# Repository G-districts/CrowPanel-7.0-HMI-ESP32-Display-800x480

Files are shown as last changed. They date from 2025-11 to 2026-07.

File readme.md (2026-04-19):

### 1, Product picture

7.0_hmi_esp32_display

### 2, Product version number

| | Hardware | Software | Remark |
| ---- | --- | --- | --- |
| 1 | V1.0 | V1.0 | old |
| 1 | V2.0 | V2.0 | old |
| 1 | V3.0 | V3.0 | latest |

**Version 2.0** adds an automatic download feature over Version 1.0, eliminating the need to press boot+reset again before downloading the program.

**Version 3.0** adds touch timing control based on Version 2.0 to prevent touch failures. When writing programs, you need to build upon the Version 2.0 program to implement the timing control logic.

  PCA9557 Out;
  
  Out.reset();
  
  Out.setMode(IO_OUTPUT);  
  
  Out.setState(IO0, IO_LOW);
  
  Out.setState(IO1, IO_LOW);
  
  delay(20);
  
  Out.setState(IO0, IO_HIGH);
  
  delay(100);
  
  Out.setMode(IO1, IO_INPUT);

### 3, product information

- Model: 7.0 inch -CrowPanel ESP32 display
- Main Processor: ESP32-S3-WROOM-1-N4R8
- Resolution: 800*480
- Flash: 4MB
- PSRAM:8MB
- Touch Type: Capacitive Touch Screen
- Display Type: TN Panel
- Screen: TFT-LCD Screen
- Display driver: EK9716BD3 & EK73002ACGB
- External power supply: DC5V-2A
- Interface: 2\*UART0,2\*GPIO,2\*I2C,1\*Battery
- Button: BOOT Button and Reset Button
- Active Area: 153.84\*85.63mm(W*H)
- Working Temperature: -20℃～70℃
- Storage Temperature: -30℃～80℃

### 4, Use the driver module

| Name | dependency library |
| ---- | --- |
| LVGL | lvgl/lvgl@8.3.3 |

### 5,Quick Start

##### Arduino IDE starts

1.Download the library files used by this product to the 'libraries' folder.

C:\Users\Documents\Arduino\libraries\



2.Open the Arduino IDE

arduino1

3.Open the code configuration environment and burn it



##### ESP-IDF starts

1.Right-click on an empty space in the project folder and select "Open with VS Code" to open the project.



2.In the IDF plug-in, select the port, then compile and flash



##### PlatformIO starts

1.Right-click on an empty space in the project folder and select "Open with VS Code" to open the project.



2.In the PlatformIO plug-in, select the port, then compile and flash

platformIO

##### Micropython starts

1,Right-click on an empty space in the project folder and select "Thonny" to open the project.

thonny

2,In thonny software, select the master and port, then run the program

thonny2

### 6,Folder structure.

|--3D file： Contains 3D model files (.stp) for the hardware. These files can be used for visualization, enclosure design, or integration into CAD software.

|--Datasheet: Includes datasheets for components used in the project, providing detailed specifications, electrical characteristics, and pin configurations.

|--Eagle_SCH&PCB: Contains **Eagle CAD** schematic (`.sch`) and PCB layout (`.brd`) files. These are used for circuit design and PCB manufacturing.

|--example: Provides example code and projects to demonstrate how to use the hardware and libraries. These examples help users get started quickly.

|--factory_firmware: Stores pre-compiled factory firmware that can be directly flashed onto the device. This ensures the device runs the default functionality.

|--factory_sourcecode: Contains the source code for the factory firmware, allowing users to modify and rebuild the firmware as needed.

### 7,Pin definition

class LGFX : public lgfx::LGFX_Device
{
public:

  lgfx::Bus_RGB     _bus_instance;
  lgfx::Panel_RGB   _panel_instance;

  LGFX(void)
  {

    {
      auto cfg = _bus_instance.config();
      cfg.panel = &_panel_instance;
    
      cfg.pin_d0  = GPIO_NUM_15; // B0
      cfg.pin_d1  = GPIO_NUM_7;  // B1
      cfg.pin_d2  = GPIO_NUM_6;  // B2
      cfg.pin_d3  = GPIO_NUM_5;  // B3
      cfg.pin_d4  = GPIO_NUM_4;  // B4
    
      cfg.pin_d5  = GPIO_NUM_9;  // G0
      cfg.pin_d6  = GPIO_NUM_46; // G1
      cfg.pin_d7  = GPIO_NUM_3;  // G2
      cfg.pin_d8  = GPIO_NUM_8;  // G3
      cfg.pin_d9  = GPIO_NUM_16; // G4
      cfg.pin_d10 = GPIO_NUM_1;  // G5
    
      cfg.pin_d11 = GPIO_NUM_14; // R0
      cfg.pin_d12 = GPIO_NUM_21; // R1
      cfg.pin_d13 = GPIO_NUM_47; // R2
      cfg.pin_d14 = GPIO_NUM_48; // R3
      cfg.pin_d15 = GPIO_NUM_45; // R4
    
      cfg.pin_henable = GPIO_NUM_41;
      cfg.pin_vsync   = GPIO_NUM_40;
      cfg.pin_hsync   = GPIO_NUM_39;
      cfg.pin_pclk    = GPIO_NUM_0;
      cfg.freq_write  = 15000000;
    
      cfg.hsync_polarity    = 0;
      cfg.hsync_front_porch = 40;
      cfg.hsync_pulse_width = 48;
      cfg.hsync_back_porch  = 40;
    
      cfg.vsync_polarity    = 0;
      cfg.vsync_front_porch = 1;
      cfg.vsync_pulse_width = 31;
      cfg.vsync_back_porch  = 13;
    
      cfg.pclk_active_neg   = 1;
      cfg.de_idle_high      = 0;
      cfg.pclk_idle_high    = 0;
    
      _bus_instance.config(cfg);
    }
            {
      auto cfg = _panel_instance.config();
      cfg.memory_width  = 800;
      cfg.memory_height = 480;
      cfg.panel_width  = 800;
      cfg.panel_height = 480;
      cfg.offset_x = 0;
      cfg.offset_y = 0;
      _panel_instance.config(cfg);
    }
    _panel_instance.setBus(&_bus_instance);
    setPanel(&_panel_instance);

  }
};

 #define TOUCH_GT911_SCL 20//20
 #define TOUCH_GT911_SDA 19//19

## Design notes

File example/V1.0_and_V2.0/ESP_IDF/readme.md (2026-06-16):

### Here is a case study of the esp_idf platform, for actual use please refer to the wiki link for instructions.

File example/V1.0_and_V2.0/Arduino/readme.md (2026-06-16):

### Here is a case study of the arduino platform, for actual use please refer to the wiki link for instructions.

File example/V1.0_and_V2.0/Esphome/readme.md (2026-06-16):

### Here is a case study of the esphome platform, for actual use please refer to the wiki link for instructions.

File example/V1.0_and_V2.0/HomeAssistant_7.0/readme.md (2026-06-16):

# Libraries Overview

## **Adafruit_Sensor-master**
Adafruit Sensor Library provides drivers for various sensors such as accelerometers, gyroscopes, and more.

## **Arduino_GFX**
Arduino GFX is a library designed for rendering graphics on displays connected to Arduino boards.

## **async-mqtt-client-develop**
Async MQTT Client Development Library enables asynchronous communication with MQTT brokers using non-blocking code suitable for embedded systems.

## **AsyncTCP-master**
Async TCP Master implements an asynchronous TCP/IP stack allowing efficient network programming without blocking the main loop of your program.

## **Crowbits_DHT20**
Crowbits DHT20 Library offers support for interfacing with DHT20 temperature and humidity sensors via I2C protocol.

## **DHT-sensor-library-master**
DHT Sensor Library Master facilitates reading data from DHT series digital temperature & humidity sensors through GPIO pins on microcontrollers.

## **FT6236**
FT6236 Driver Library handles touch screen input detection and processing based on capacitive touch technology often found in smartphones and tablets.

## **gt911-arduino**
GT911 Arduino Library manages touch panel inputs specifically tailored towards GT911 chipsets commonly utilized in touchscreen applications.

## **LovyanGFX**
Lovyan GFX serves as a comprehensive graphic library capable of driving multiple kinds of displays including TFTs, OLEDs among others while offering advanced features like anti-aliasing text rendering.

## **lvgl**
LVGL stands for Light and Versatile Graphics Library which focuses on providing high-performance graphical user interface solutions primarily targeted at resource-constrained environments yet scalable enough for complex GUI designs.

## **TFT_eSPI**
TFT eSPI specializes in controlling ILI9341-driven TFT displays featuring built-in SD card reader functionality along with touch screen capabilities if applicable.

## **U8g2**
U8g2 is another lightweight graphics library intended mainly for monochrome LCD/LED displays but also supports some color screens; it's known for its simplicity and ease-of-use making it ideal for beginners entering into graphical display projects.

## **UI**
User Interface component likely refers to either a set of pre-designed elements ready-to-use within your project or could denote custom-coded components forming part of larger application’s visual presentation layer.

## **XPT2046_Touchscreen**
XPT2046 Touchscreen Library deals with resistive touchscreens employing XPT2046 controller IC enabling precise touch location tracking essential for interactive interfaces.

## **lv_conf.h**
LvConf.h represents configuration header file where users can customize settings pertaining to LVGL library according to their specific requirements regarding display characteristics, memory allocation strategies amongst other tunable aspects influencing overall performance and behavior of graphical outputs generated by said library.

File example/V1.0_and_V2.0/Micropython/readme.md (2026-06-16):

### Here is a case study of the micropython platform, for actual use please refer to the wiki link for instructions.

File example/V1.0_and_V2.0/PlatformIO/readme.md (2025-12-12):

### Here is a case study of the platformIO platform, for actual use please refer to the wiki link for instructions.
## Complete code link：https://www.elecrow.com/download/product/CrowPanel/ESP32-HMI/7.0-DIS08070H/PlatformIO/CrowPanel_ESP32_7.0_PlatformIO_Project.zip

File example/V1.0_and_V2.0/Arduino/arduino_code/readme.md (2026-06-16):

# Libraries Overview

## **Adafruit_BusIO**
Adafruit BusIO is a library that provides an interface for communicating with various I/O devices over different buses like I2C, SPI, etc.

## **Adafruit_GFX_Library**
The Adafruit GFX Library is used for drawing graphics on displays connected to microcontrollers. It supports many different display types including OLEDs, LCDs, and e-paper displays.

## **Adafruit_SSD1306**
This library allows you to control SSD1306-based OLED displays using Arduino or other compatible platforms.

## **BLE**
Bluetooth Low Energy (BLE) libraries are typically used for wireless communication between devices at low power consumption levels.

## **Crowbits_DHT20**
A library specifically designed for reading data from DHT20 digital temperature and humidity sensors.

## **EEPROM**
EEPROM stands for Electrically Erasable Programmable Read-Only Memory; this library enables storing small amounts of persistent data even when the device loses power.

## **ESP32-audioI2S-master**
This library facilitates audio playback through I2S protocol on ESP32 microcontrollers, often used in projects involving sound output.

## **FFat**
FFat refers to FatFs, a generic FAT filesystem module for small embedded systems. This library helps manage storage on SD cards or similar media.

## **FS**
File System libraries provide functions for managing files and directories within the system's storage.

## **gt911-arduino-main**
Library for integrating GT911 capacitive touch screen controllers into Arduino projects.

## **LovyanGFX**
LovyanGFX is another graphics library aimed at providing high-performance rendering capabilities across various display technologies.

## **lvgl**
LVGL (Light and Versatile Graphics Library) is a free and open-source graphics library that offers advanced GUI elements suitable for embedded systems.

## **PCA9557**
PCA9557 is an I/O expander chip controlled via I2C bus - its corresponding library would allow controlling multiple GPIO pins remotely.

## **SD**
Standard SD card library enabling read/write operations on Secure Digital memory cards.

## **SD_MMC**
Similar to above but may include additional features or optimizations specific to certain models of SD/MMC cards.

## **SPI**
Serial Peripheral Interface (SPI) is a synchronous serial communication interface specification used by microcontrollers to communicate with peripheral devices such as sensors, displays, etc.

## **SPIFFS**
SPI Flash File System – a lightweight file system designed primarily for use with flash memories found in many IoT devices.

## **Ticker**
Ticker libraries usually offer precise timing functionalities useful in scheduling tasks or generating interrupts based on time intervals.

## **UI**
User Interface components could encompass anything from visual design assets to interactive elements facilitating user interaction with hardware/software applications.

## **WiFi**
Libraries dealing with WiFi connectivity protocols enabling internet access via wireless networks.

## **WiFiClientSecure**
Enhanced version of WiFiClient incorporating security measures like SSL/TLS encryption ensuring secure connections over Wi-Fi networks.

## **Wire**
Two-wire interface (TWI), also known as Inter-Integrated Circuit (I²C), is a bidirectional serial computer bus used for attaching lower-speed peripherals to processors and microcontrollers.

## **lv_conf.h**
Configuration file for LVGL library defining parameters like display resolution, color format, font sizes, widget styles, event handling mechanisms amongst others tailored per application needs.

## **UI-7.0-BLUE.rar**
This appears to be a compressed archive containing resources related to User Interface version 7.0 themed in blue colors possibly including icons, images, layouts or other graphical content necessary for creating consistent look-and-feel across application interfaces.

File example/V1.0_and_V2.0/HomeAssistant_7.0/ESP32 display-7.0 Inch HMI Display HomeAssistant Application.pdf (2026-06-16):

# Home Assistant Raspberry Pi Server Configuration

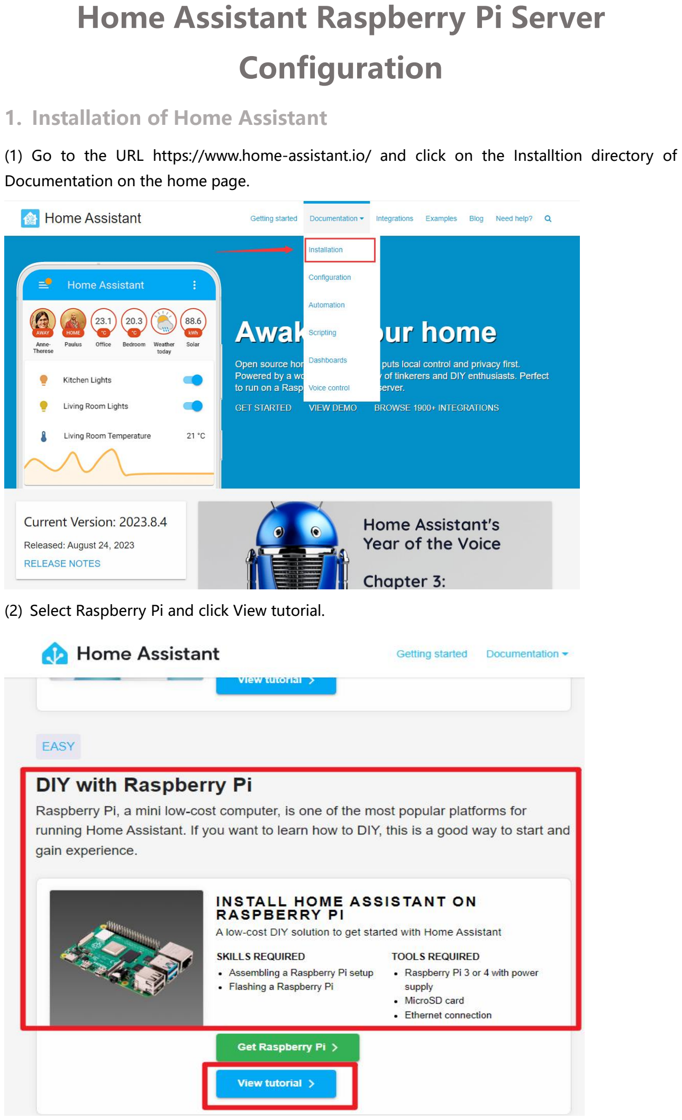
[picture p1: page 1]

## 1. Installation of Home Assistant

(1) Go to the URL https://www.home-assistant.io/ and click on the Installtion directory of Documentation on the home page.
(2) Select Raspberry Pi and click View tutorial.

## 2. Write the image to the SD card

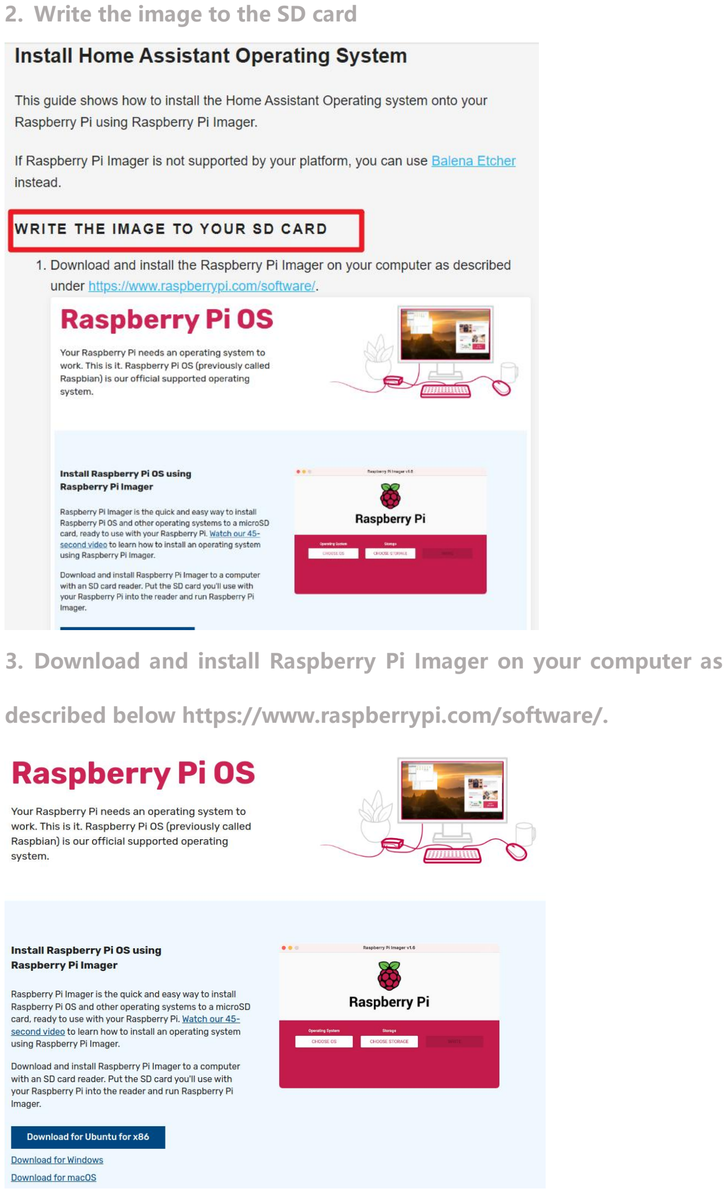
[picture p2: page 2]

## 3. Download and install Raspberry Pi Imager on your computer as

described below https://www.raspberrypi.com/software/.

4. Open Raspberry Pi Imager and select your Raspberry Pi device.

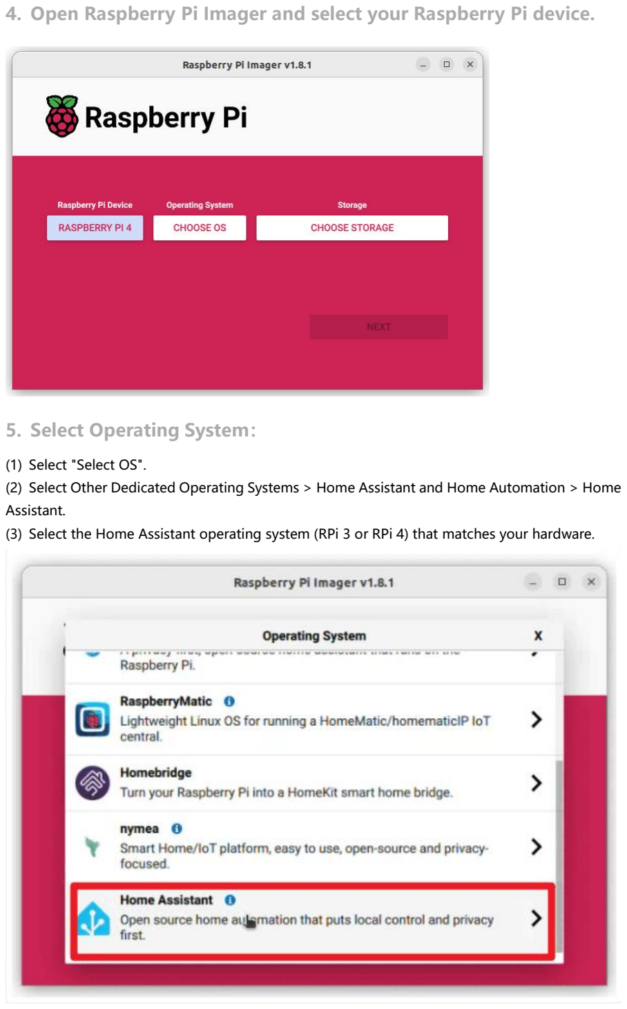
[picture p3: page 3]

## 5. Select Operating System：

(1) Select "Select OS". (2) Select Other Dedicated Operating Systems > Home Assistant and Home Automation > Home

Assistant. (3) Select the Home Assistant operating system (RPi 3 or RPi 4) that matches your hardware.

## 6. Select storage:

(1)Insert the SD card into the computer. Note:The contents of the card will be overwritten. (2)Select your SD card.

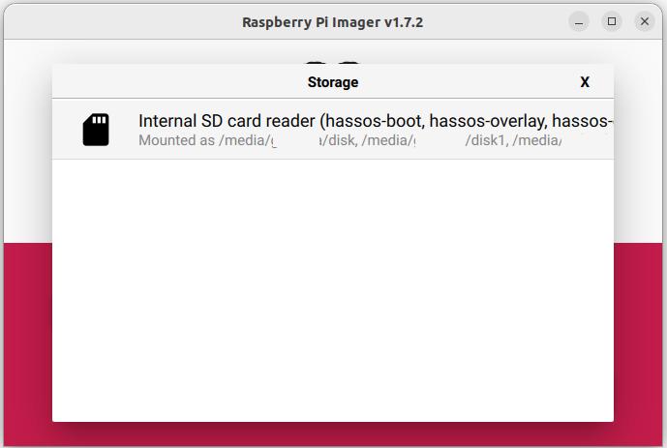
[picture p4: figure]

## 7. Write the installer to the SD card:

(1) To start the process, select Next. (2) Wait for the Home Assistant OS to write to the SD card.

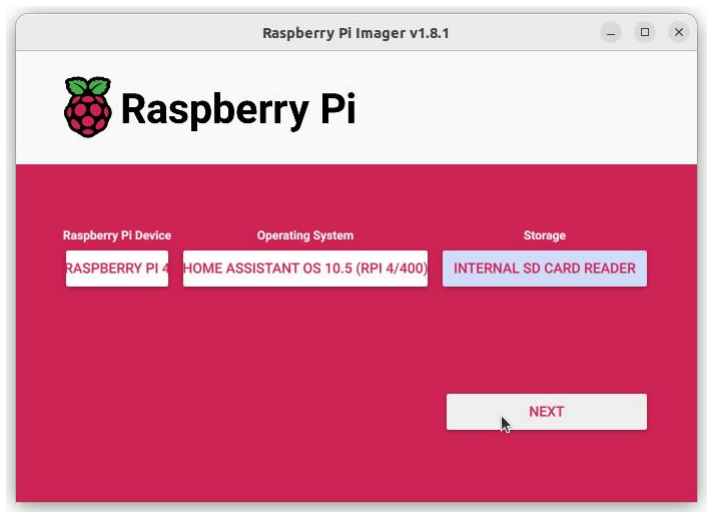
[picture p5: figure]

## 8. Eject the SD card. 9. Start Raspberry Pi

(1) Insert the SD card into the Raspberry Pi. (2) Plug in the Ethernet cable and make sure the Raspberry Pi is connected to the same network

as your computer.

(3) Connect the power supply and start the device. 10. start the Raspberry Pi, start after the completion of we can see

## the LAN ip address and port information, 8123 is the management

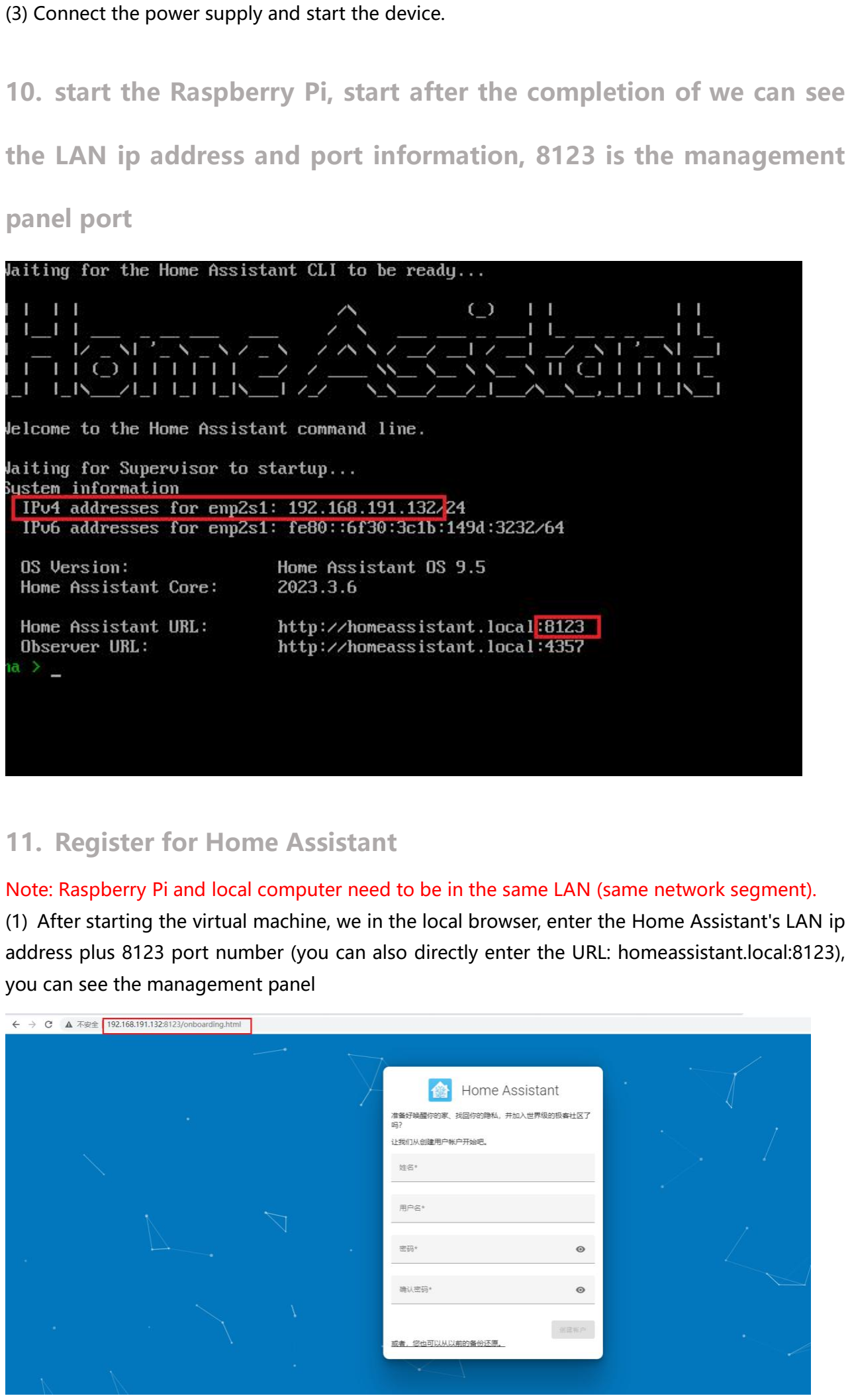
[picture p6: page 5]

## panel port

## 11. Register for Home Assistant

Note: Raspberry Pi and local computer need to be in the same LAN (same network segment). (1) After starting the virtual machine, we in the local browser, enter the Home Assistant's LAN ip

address plus 8123 port number (you can also directly enter the URL: homeassistant.local:8123), you can see the management panel

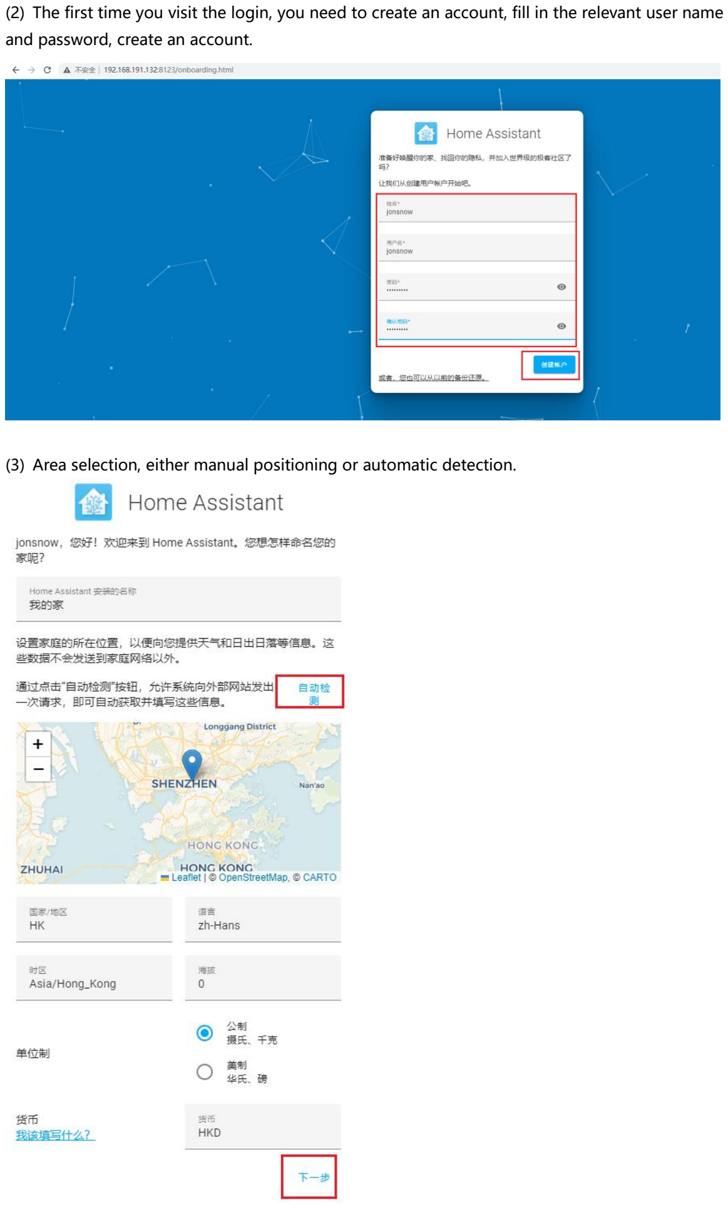
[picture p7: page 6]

(2) The first time you visit the login, you need to create an account, fill in the relevant user name and password, create an account.
(3) Area selection, either manual positioning or automatic detection.

(4) Next click Next by default

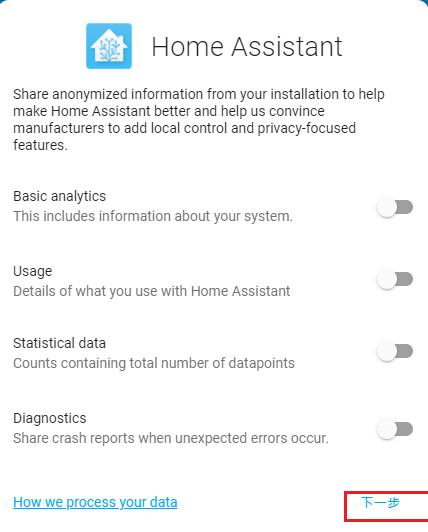
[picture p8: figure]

(5) Then click Finish, here prompted to add a smart device, you can click Finish, and then set up your own settings.

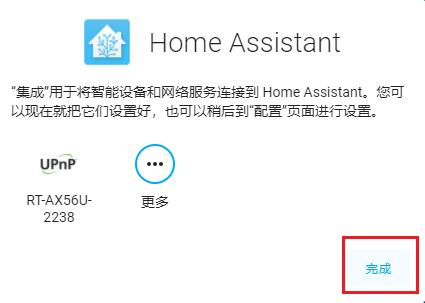
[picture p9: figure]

(6) Then you're in the control panel screen

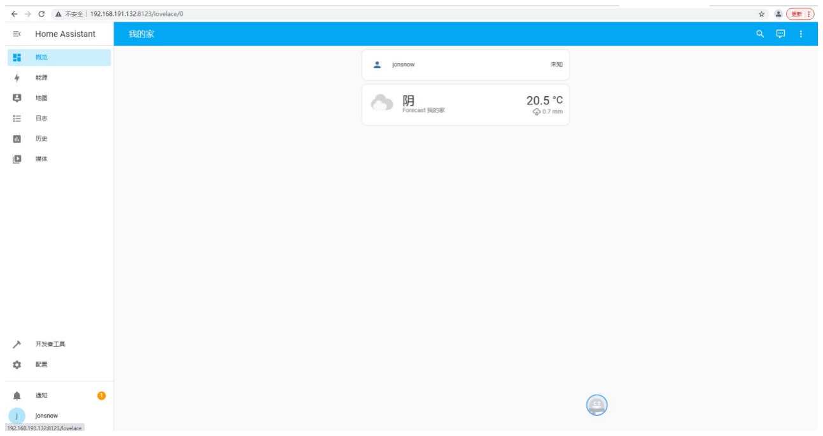
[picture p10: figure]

## 12. Configuring MQTT

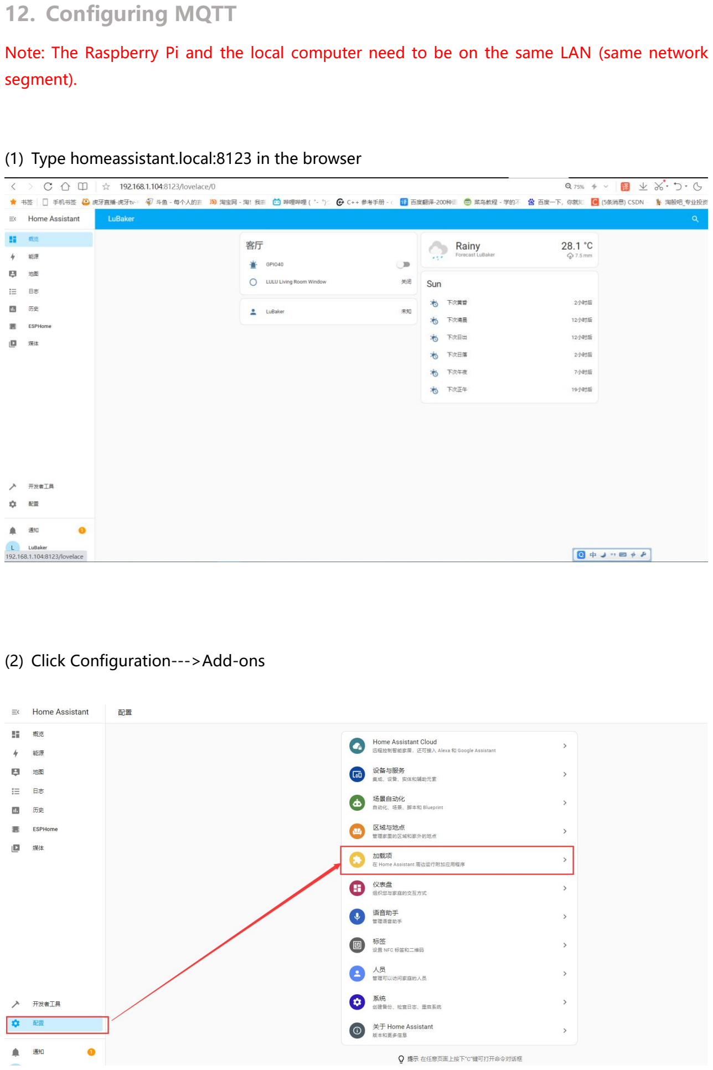
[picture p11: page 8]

Note: The Raspberry Pi and the local computer need to be on the same LAN (same network segment).

(1) Type homeassistant.local:8123 in the browser
(2) Click Configuration--->Add-ons

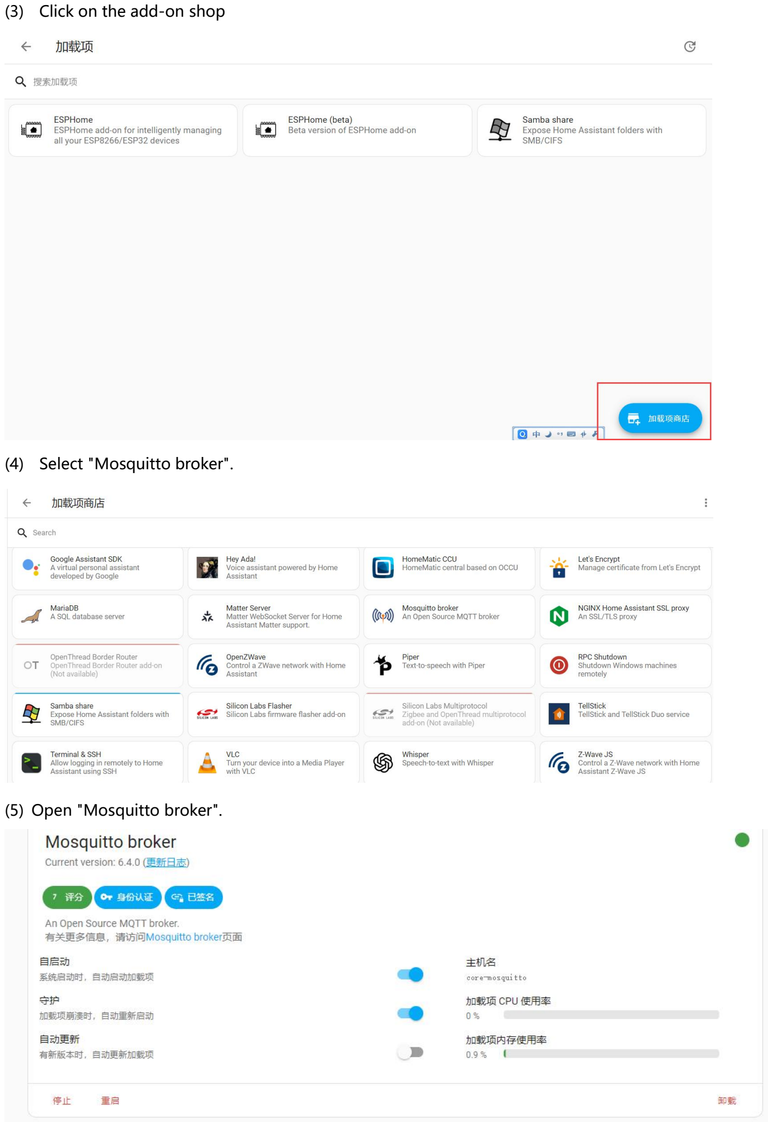
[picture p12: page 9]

(3) Click on the add-on shop
(4) Select "Mosquitto broker".
(5) Open "Mosquitto broker".

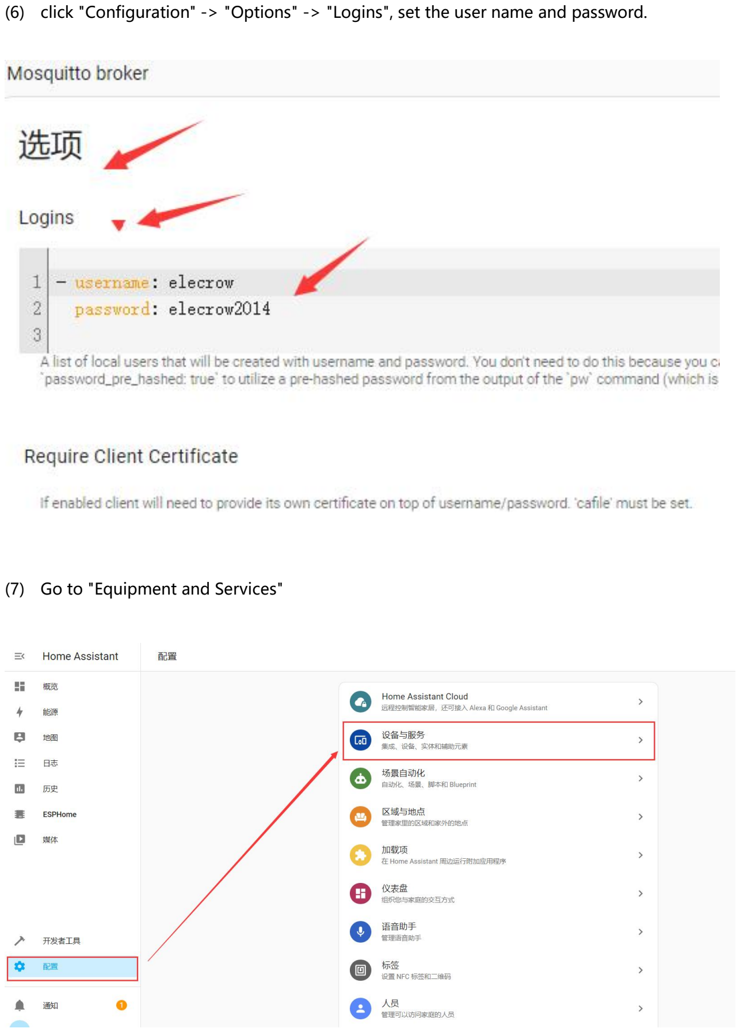
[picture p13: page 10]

(6) click "Configuration" -> "Options" -> "Logins", set the user name and password.
(7) Go to "Equipment and Services"

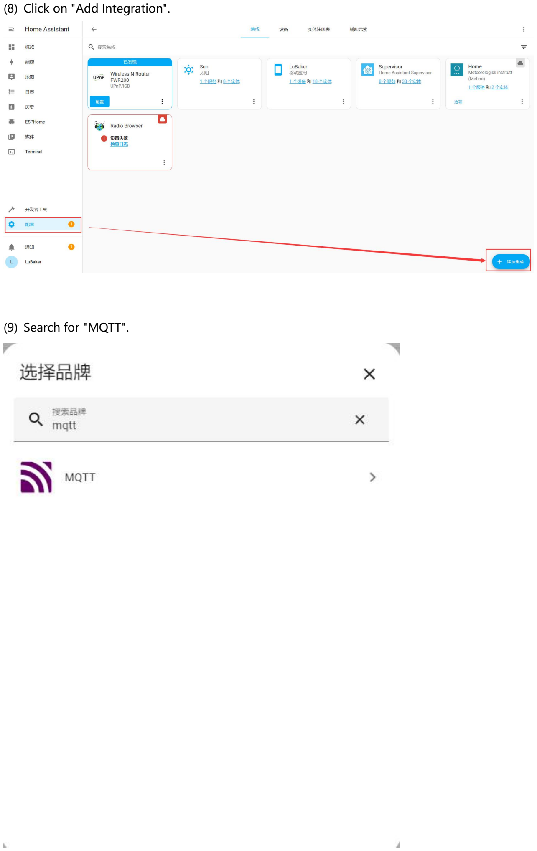
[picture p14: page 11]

(8) Click on "Add Integration".
(9) Search for "MQTT".

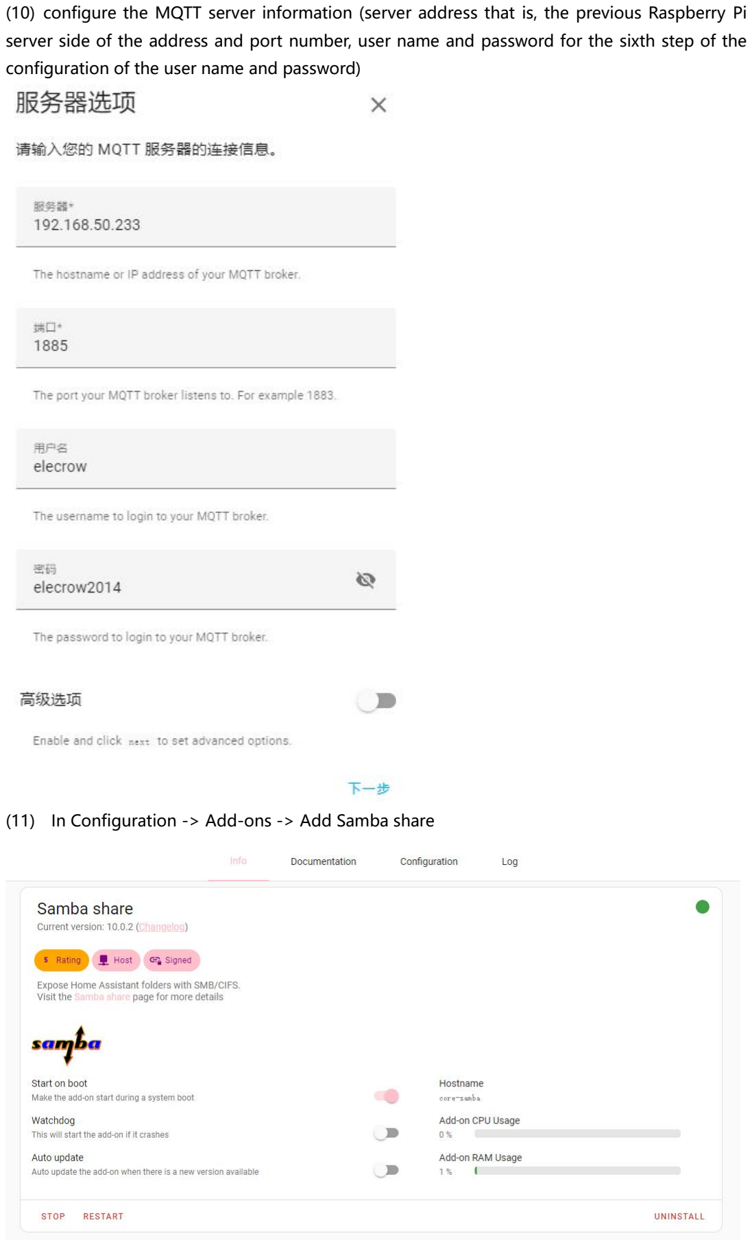
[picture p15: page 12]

(10) configure the MQTT server information (server address that is, the previous Raspberry Pi server side of the address and port number, user name and password for the sixth step of the configuration of the user name and password)
(11) In Configuration -> Add-ons -> Add Samba share

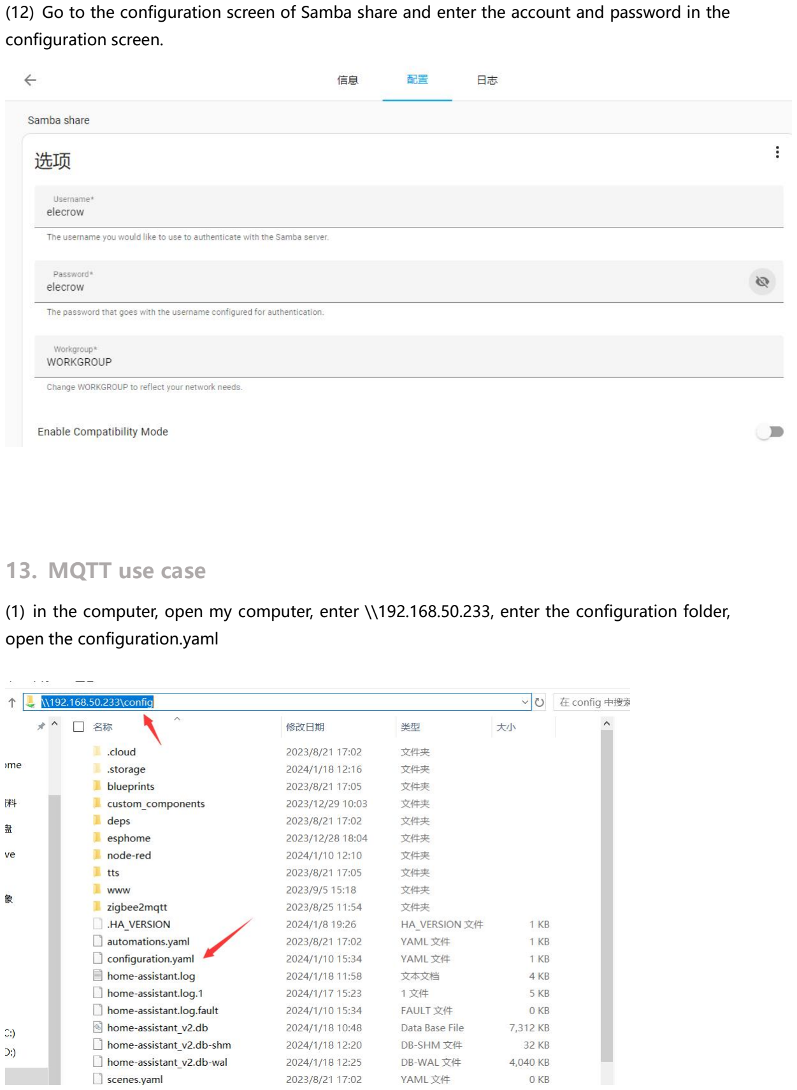
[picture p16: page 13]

(12) Go to the configuration screen of Samba share and enter the account and password in the configuration screen.

## 13. MQTT use case

(1) in the computer, open my computer, enter \\192.168.50.233, enter the configuration folder, open the configuration.yaml

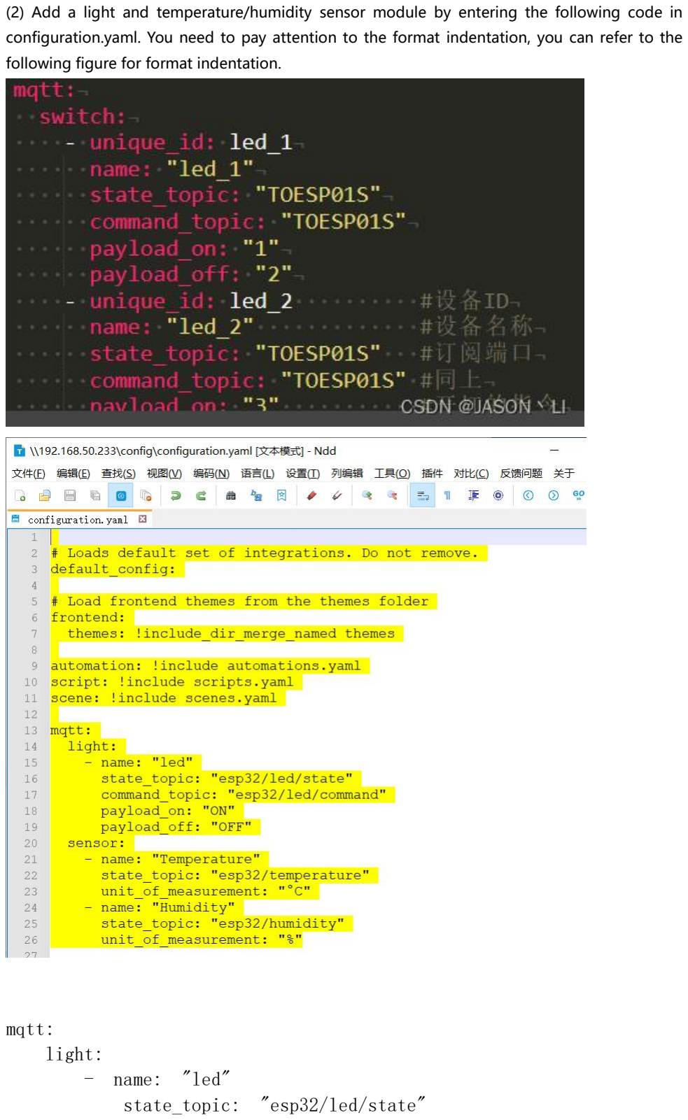
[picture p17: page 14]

(2) Add a light and temperature/humidity sensor module by entering the following code in configuration.yaml. You need to pay attention to the format indentation, you can refer to the following figure for format indentation.

mqtt:
light:
- name: "led"
state_topic: "esp32/led/state"

command_topic: "esp32/led/command" payload_on: "ON"
payload_off: "OFF"
sensor:
- name: "Temperature"
state_topic: "esp32/temperature" unit_of_measurement: "°C"
- name: "Humidity"
state_topic: "esp32/humidity" unit_of_measurement: "%" Above belongs to the configuration in yaml file to enable lights and sensors with brightness. For
more knowledge refer to the link: https://www.home-assistant.io/integrations/light.mqtt/. 14. After | saving | the | above | code, | go | to | the | main

## interface->Overview->Edit Dashboard->Add Card->Select the entity

## just written in configuration.yaml in the card->Click Finish to

complete the addition.

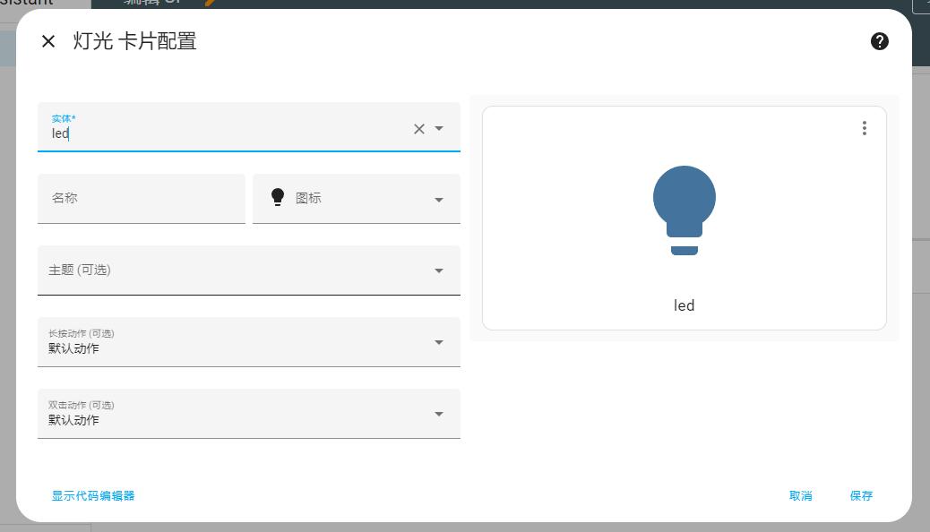
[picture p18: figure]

## 15. Burn the corresponding arduino code for the screen. (Refer to

## "7.0inch_Squareline_Demo Download Introduction" document)

## 16. Server-side effect display

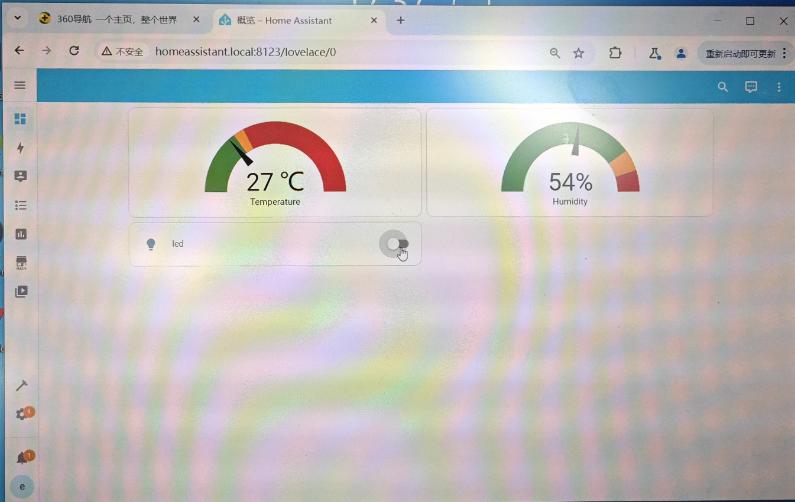
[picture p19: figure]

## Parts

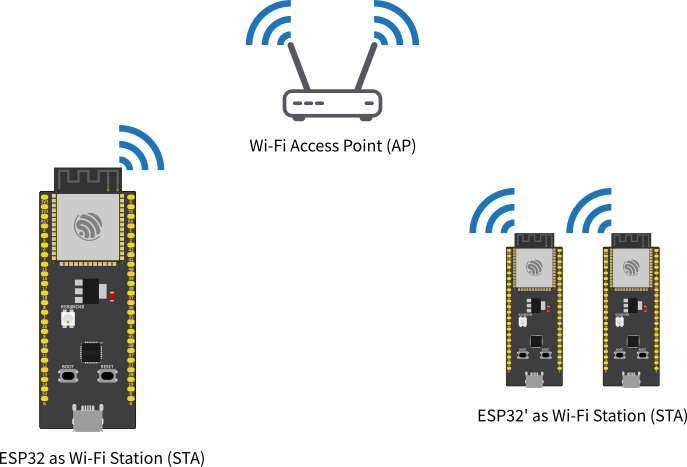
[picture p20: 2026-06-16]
example/V1.0_and_V2.0/ESP_IDF/CrowPanel_ESP32_7.0/components/arduino-esp32-master/docs/source/_static/wifi_esp32_sta.png

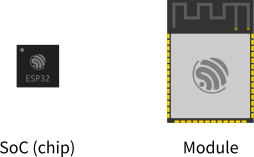
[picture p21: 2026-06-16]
example/V1.0_and_V2.0/ESP_IDF/CrowPanel_ESP32_7.0/components/arduino-esp32-master/docs/source/_static/soc-module.png

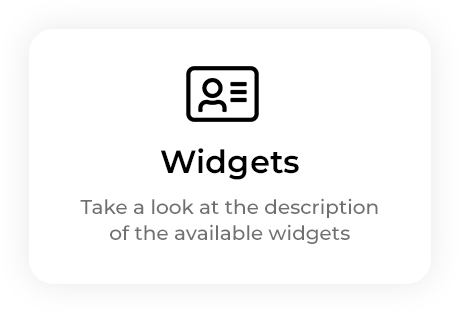
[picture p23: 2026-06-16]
example/V1.0_and_V2.0/ESP_IDF/CrowPanel_ESP32_7.0/components/lvgl-3/docs/_static/img/home_5.png

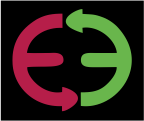
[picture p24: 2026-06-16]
example/V1.0_and_V2.0/ESP_IDF/CrowPanel_ESP32_7.0/components/lvgl-3/src/examples/assets/toppic.png

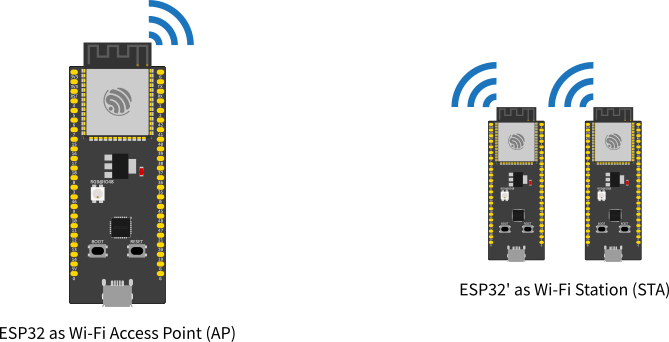
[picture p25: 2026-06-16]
example/V1.0_and_V2.0/ESP_IDF/CrowPanel_ESP32_7.0/components/arduino-esp32-master/docs/source/_static/wifi_esp32_ap.png

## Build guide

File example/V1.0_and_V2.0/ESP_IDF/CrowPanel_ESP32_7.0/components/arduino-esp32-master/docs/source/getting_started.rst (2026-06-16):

###############
Getting Started
###############

About Arduino ESP32
-------------------

Welcome to the Arduino ESP32 support documentation! Here you will find important information on how to use the project.

First Things First
------------------

.. note::
    Before continuing, we must be clear that this project is supported by `Espressif Systems`_ and the community.
    Everyone is more than welcome to contribute back to this project.

ESP32 is a single 2.4 GHz Wi-Fi-and-Bluetooth SoC (System On a Chip) designed by `Espressif Systems`_.

ESP32 is designed for mobile, wearable electronics, and Internet-of-Things (IoT) applications. It features all the state-of-the-art characteristics 
of low-power chips, including fine-grained clock gating, multiple power modes,and dynamic power scaling. For instance, in a low-power IoT sensor 
hub application scenario, ESP32 is woken-up periodically and only when a specified condition is detected. Low-duty cycle is used to minimize the 
amount of energy that the chip expends. 

The output of the power amplifier is also adjustable, thus contributing to an optimal trade-off between communication range, data rate and 
power consumption.

The ESP32 series is available as a chip or module.

.. _supported_socs:

Supported SoC's
---------------

Here are the ESP32 series supported by the Arduino-ESP32 project:

======== ====== =========== ===================================
SoC      Stable Development Datasheet
======== ====== =========== ===================================
ESP32    Yes    Yes         `ESP32`_
ESP32-S2 Yes    Yes         `ESP32-S2`_
ESP32-C3 Yes    Yes         `ESP32-C3`_
ESP32-S3 No     Yes         `ESP32-S3`_
======== ====== =========== ===================================

See `Boards <boards/boards.html>`_ for more details about ESP32 development boards.

Arduino Core Reference
----------------------

This documentation is built on the ESP32 and we are not going to cover the common Arduino API. To see the Arduino reference documentation, 
please consider reading the official documentation.

Arduino Official Documentation: `Arduino Reference`_.

Supported Operating Systems
---------------------------

+-------------------+-------------------+-------------------+
|     |       |       |
+-------------------+-------------------+-------------------+
| Windows           | Linux             | macOS             |
+-------------------+-------------------+-------------------+





Supported IDEs
---------------------------

Here is the list of supported IDE for Arduino ESP32 support integration.

+-------------------+-------------------+
|     |         |
+-------------------+-------------------+
| Arduino IDE       | PlatformIO        |
+-------------------+-------------------+




See `Installing Guides <installing.html>`_ for more details on how to install the Arduino ESP32 support.

Support
-------

This is an open project and it's supported by the community. Fell free to ask for help in one of the community channels.

Community
---------

The Arduino community is huge! You can find a lot of useful content on the Internet.
Here are some community channels where you may find information and ask for some help, if needed.

- `ESP32 Forum`_: Official Espressif Forum.
- `ESP32 Forum - Arduino`_: Official Espressif Forum for Arduino related discussions.
- `ESP32 Forum - Hardware`_: Official Espressif Forum for Hardware related discussions.
- `Gitter`_
- `Espressif MCUs (Discord)`_
- `ESP32 on Reddit`_

Issues Reporting
----------------

Before opening a new issue, please read this: 

Be sure to search for a similar reported issue. This avoids duplicating or creating noise in the GitHub Issues reporting.
We also have the troubleshooting guide to save your time on the most common issues reported by users.

For more details about creating new Issue, see the `Issue Template <https://github.com/espressif/arduino-esp32/blob/master/.github/ISSUE_TEMPLATE/Issue-report.yml>`_.

If you have any new idea, see the `Feature request Template <https://github.com/espressif/arduino-esp32/blob/master/.github/ISSUE_TEMPLATE/Feature-request.yml>`_.

First Steps
-----------

Here are the first steps to get the Arduino ESP32 support running.

To install Arduino-ESP32, please see the dedicated section on the Installation guide. We recommend you install it using the boards manager.

.. toctree::
    :maxdepth: 2
    
    How to Install <installing>
    Development Boards <boards/boards>

Examples
--------

After installing the toolchain into your environment, you will be able to see all the dedicated examples for the ESP32. These examples are located
in the examples menu or inside each library folder.

    https://github.com/espressif/arduino-esp32/tree/master/libraries

.. include:: common/datasheet.inc

Resources
---------

.. _Espressif Systems: https://www.espressif.com 
.. _Espressif Product Selector: https://products.espressif.com/
.. _Arduino.cc: https://www.arduino.cc/en/Main/Software
.. _Arduino Reference: https://www.arduino.cc/reference/en/
.. _ESP32 Forum: https://esp32.com
.. _ESP32 Forum - Arduino: https://esp32.com/viewforum.php?f=19
.. _ESP32 Forum - Hardware: https://esp32.com/viewforum.php?f=12
.. _Gitter: https://gitter.im/espressif/arduino-esp32
.. _Adafruit (Discord): https://discord.gg/adafruit
.. _Espressif MCUs (Discord): https://discord.gg/nKxMTnkD
.. _ESP32 on Reddit: https://www.reddit.com/r/esp32

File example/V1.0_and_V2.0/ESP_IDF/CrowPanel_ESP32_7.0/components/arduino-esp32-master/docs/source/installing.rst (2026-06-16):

##########
Installing
##########

This guide will show how to install the Arduino-ESP32 support.

Before Installing
-----------------

We recommend you install the support using your favorite IDE, but other options are available depending on your operating system. 
To install Arduino-ESP32 support, you can use one of the following options.

Installing using Arduino IDE
----------------------------



This is the way to install Arduino-ESP32 directly from the Arduino IDE.

.. note::
   For overview of SoC's support, take a look on `Supported Soc's table <https://docs.espressif.com/projects/arduino-esp32/en/latest/getting_started.html#supported-soc-s>`_ where you can find if the particular chip is under stable or development release.

- Stable release link::

   https://raw.githubusercontent.com/espressif/arduino-esp32/gh-pages/package_esp32_index.json

- Development release link::

   https://raw.githubusercontent.com/espressif/arduino-esp32/gh-pages/package_esp32_dev_index.json

.. note::
   Starting with the Arduino IDE version 1.6.4, Arduino allows installation of third-party platform 
   packages using Boards Manager. We have packages available for Windows, macOS, and Linux.

To start the installation process using the Boards Managaer, follow these steps:

-  Install the current upstream Arduino IDE at the 1.8 level or later. The current version is at the `arduino.cc`_ website.

-  Start Arduino and open the Preferences window.



-  Enter one of the release links above into *Additional Board Manager URLs* field. You can add multiple URLs, separating them with commas.



-  Open Boards Manager from Tools > Board menu and install *esp32* platform (and do not forget to select your ESP32 board from Tools > Board menu after installation).



- Restart Arduino IDE.

Installing using PlatformIO
---------------------------



PlatformIO is a professional collaborative platform for embedded development. It has out-of-the-box support for ESP32 SoCs and allows working with Arduino ESP32 as well as ESP-IDF from Espressif without changing your development environment. PlatformIO includes lots of instruments for the most common development tasks such as debugging, unit testing, and static code analysis.

A detailed overview of the PlatformIO ecosystem and its philosophy can be found in `the official documentation <https://docs.platformio.org/en/latest/core/index.html>`_.

PlatformIO can be used in two flavors:

- `PlatformIO IDE <https://platformio.org/platformio-ide>`_ is a toolset for embedded C/C++ development available on Windows, macOS and Linux platforms

- `PlatformIO Core (CLI) <https://docs.platformio.org/en/latest/core/index.html>`_ is a command-line tool that consists of a multi-platform build system, platform and library managers and other integration components. It can be used with a variety of code development environments and allows integration with cloud platforms and web services

To install PlatformIO, you can follow this Getting Started, provided at `docs.platformio.org`_.

Using the stable code
*********************

.. note::
   A detailed overview of supported development boards, examples and frameworks can be found on `the official Espressif32 dev-platform page <https://registry.platformio.org/platforms/platformio/espressif32>`_ in the PlatformIO Registry.

The most reliable and easiest way to get started is to use the latest stable version of the ESP32 development platform that passed all tests/verifications and can be used in production.

Create a new project and select one of the available boards. You can change after by changing the `platformio.ini <https://docs.platformio.org/en/latest/projectconf/index.html>`_ file.

- For ESP32

.. code-block:: bash

   [env:esp32dev]
   platform = espressif32
   board = esp32dev
   framework = arduino

- For ESP32-S2 (ESP32-S2-Saola-1 board)

.. code-block:: bash

   [env:esp32-s2-saola-1]
   platform = espressif32
   board = esp32-s2-saola-1
   framework = arduino

- For ESP32-C3 (ESP32-C3-DevKitM-1 board)

.. code-block:: bash

   [env:esp32-c3-devkitm-1]
   platform = espressif32
   board = esp32-c3-devkitm-1
   framework = arduino

How to update to the latest code
********************************

To test the latest Arduino ESP32, you need to change your project *platformio.ini* accordingly.
The following configuration uses the upstream version of the Espressif development platform and the latest Arduino core directly from the Espressif GitHub repository:

.. code-block:: bash

   [env:esp32-c3-devkitm-1]
   platform = https://github.com/platformio/platform-espressif32.git
   board = esp32-c3-devkitm-1
   framework = arduino
   platform_packages =
       framework-arduinoespressif32 @ https://github.com/espressif/arduino-esp32#master

To get more information about PlatformIO, see the following links:

- `PlatformIO Core (CLI) <https://docs.platformio.org/en/latest/core/index.html>`_

- `PlatformIO Home <https://docs.platformio.org/en/latest/home/index.html>`_

- `Tutorials and Examples <https://docs.platformio.org/en/latest/tutorials/index.html>`_

- `Library Management <https://docs.platformio.org/en/latest/librarymanager/index.html>`_

Windows (manual installation)
-----------------------------

.. warning:: Arduino ESP32 core v2.x.x cannot be used on Windows 8.x x86 (32 bits), Windows 7 or earlier. The Windows 32 bits OS is no longer supported by this toolchain.

   The Arduino ESP32 v1.0.6 still works on WIN32. You might want to install python 3.8.x because it is the latest release supported by Windows 7.

Steps to install Arduino ESP32 support on Windows:

**Step 1**

1. Download and install the latest Arduino IDE ``Windows Installer`` from [arduino.cc](https://www.arduino.cc/en/Main/Software)
2. Download and install Git from [git-scm.com](https://git-scm.com/download/win)
3. Start ``Git GUI`` and do the following steps:

- Select ``Clone Existing Repository``



- Select source and destination
   - Sketchbook Directory: Usually ``C:/Users/[YOUR_USER_NAME]/Documents/Arduino`` and is listed underneath the "Sketchbook location" in Arduino preferences.
   - Source Location: ``https://github.com/espressif/arduino-esp32.git``
   - Target Directory: ``[ARDUINO_SKETCHBOOK_DIR]/hardware/espressif/esp32``
   - Click ``Clone`` to start cloning the repository

**Step 2**



**Step 3**



- open a `Git Bash` session pointing to ``[ARDUINO_SKETCHBOOK_DIR]/hardware/espressif/esp32`` and execute ```git submodule update --init --recursive``` 
- Open ``[ARDUINO_SKETCHBOOK_DIR]/hardware/espressif/esp32/tools`` and double-click ``get.exe``

**Step 4**



- When ```get.exe``` finishes, you should see the following files in the directory

**Step 5**



1. Plug your ESP32 board and wait for the drivers to install (or install manually any that might be required)
2. Start Arduino IDE
3. Select your board in ``Tools > Board`` menu
4. Select the COM port that the board is attached to
5. Compile and upload (You might need to hold the boot button while uploading)



How to update to the latest code
********************************

1. Start ``Git GUI`` and you should see the repository under ``Open Recent Repository``. Click on it!



1. From menu ``Remote`` select ``Fetch from`` > ``origin``



1. Wait for git to pull any changes and close ``Git GUI``
2. Open ``[ARDUINO_SKETCHBOOK_DIR]/hardware/espressif/esp32/tools`` and double-click ``get.exe``



Linux
-----



Debian/Ubuntu
*************

- Install latest Arduino IDE from `arduino.cc`_.

- Open Terminal and execute the following command (copy -> paste and hit enter):

.. code-block:: bash

   sudo usermod -a -G dialout $USER && \
   sudo apt-get install git && \
   wget https://bootstrap.pypa.io/get-pip.py && \
   sudo python3 get-pip.py && \
   sudo pip3 install pyserial && \
   mkdir -p ~/Arduino/hardware/espressif && \
   cd ~/Arduino/hardware/espressif && \
   git clone https://github.com/espressif/arduino-esp32.git esp32 && \
   cd esp32/tools && \
   python3 get.py

- Restart Arduino IDE.

- If you have Arduino installed to ~/, modify the installation as follows, beginning at `mkdir -p ~/Arduino/hardware`:

.. code-block:: bash

   cd ~/Arduino/hardware
   mkdir -p espressif && \
   cd espressif && \
   git clone https://github.com/espressif/arduino-esp32.git esp32 && \
   cd esp32/tools && \
   python3 get.py

Fedora
******

- Install the latest Arduino IDE from `arduino.cc`_.

.. note::
   Command ``$ sudo dnf -y install arduino`` will most likely install an older release.

- Open Terminal and execute the following command (copy -> paste and hit enter):

.. code-block:: bash

   sudo usermod -a -G dialout $USER && \
   sudo dnf install git python3-pip python3-pyserial && \
   mkdir -p ~/Arduino/hardware/espressif && \
   cd ~/Arduino/hardware/espressif && \
   git clone https://github.com/espressif/arduino-esp32.git esp32 && \
   cd esp32/tools && \
   python get.py

- Restart Arduino IDE.

openSUSE
********

- Install the latest Arduino IDE from `arduino.cc`_.

- Open Terminal and execute the following command (copy -> paste and hit enter):

.. code-block:: bash

   sudo usermod -a -G dialout $USER && \
   if [ `python --version 2>&1 | grep '2.7' | wc -l` = "1" ]; then \
   sudo zypper install git python-pip python-pyserial; \
   else \
   sudo zypper install git python3-pip python3-pyserial; \
   fi && \
   mkdir -p ~/Arduino/hardware/espressif && \
   cd ~/Arduino/hardware/espressif && \
   git clone https://github.com/espressif/arduino-esp32.git esp32 && \
   cd esp32/tools && \
   python get.py

- Restart Arduino IDE.

macOS
-----

- Install the latest Arduino IDE from `arduino.cc`_.

- Open Terminal and execute the following command (copy -> paste and hit enter):

.. code-block:: bash

   mkdir -p ~/Documents/Arduino/hardware/espressif && \
   cd ~/Documents/Arduino/hardware/espressif && \
   git clone https://github.com/espressif/arduino-esp32.git esp32 && \
   cd esp32/tools && \
   python get.py 

Where ``~/Documents/Arduino`` represents your sketch book location as per "Arduino" > "Preferences" > "Sketchbook location" (in the IDE once started). Adjust the command above accordingly.

- If you get the error below, install through the command line dev tools with `xcode-select --install` and try the command above again:

.. code-block:: bash

   xcrun: error: invalid active developer path (/Library/Developer/CommandLineTools), missing xcrun at: /Library/Developer/CommandLineTools/usr/bin/xcrun

- Run the command:

.. code-block:: bash

   xcode-select --install

- Try ``python3`` instead of ``python`` if you get the error: ``IOError: [Errno socket error] [SSL: TLSV1_ALERT_PROTOCOL_VERSION] tlsv1 alert protocol version (_ssl.c:590)`` when running ``python get.py``

- If you get the following error when running ``python get.py`` urllib.error.URLError: <urlopen error SSL: CERTIFICATE_VERIFY_FAILED, go to Macintosh HD > Applications > Python3.6 folder (or any other python version), and run the following scripts: Install Certificates.command and Update Shell Profile.command

- Restart Arduino IDE.

.. _Arduino.cc: https://www.arduino.cc/en/Main/Software
.. _docs.platformio.org: https://docs.platformio.org/en/latest/integration/ide/pioide.html

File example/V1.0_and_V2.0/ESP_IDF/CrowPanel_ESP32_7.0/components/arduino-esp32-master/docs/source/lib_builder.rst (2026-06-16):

###############
Library Builder
###############

About
-----

Espressif provides a `tool <https://github.com/espressif/esp32-arduino-lib-builder>`_ to simplify building your own compiled libraries for use in Arduino IDE (or your favorite IDE).

This tool can be used to change the project or a specific configuration according to your needs.

Installing
----------

To install the Library Builder into your environment, please, follow the instructions below.

- Clone the ESP32 Arduino lib builder:

.. code-block:: bash

    git clone https://github.com/espressif/esp32-arduino-lib-builder

- Go to the ``esp32-arduino-lib-builder`` folder:

.. code-block:: bash

    cd esp32-arduino-lib-builder

- Build:

.. code-block:: bash

    ./build.sh

If everything works, you may see the following message: ``Successfully created esp32 image.``

Dependencies
************

To build the library you will need to install some dependencies. Maybe you already have installed it, but it is a good idea to check before building.

- Install all dependencies (**Ubuntu**):

.. code-block:: bash

    sudo apt-get install git wget curl libssl-dev libncurses-dev flex bison gperf cmake ninja-build ccache jq

- Install Python and upgrade pip:

.. code-block:: bash

    sudo apt-get install python3
    sudo pip install --upgrade pip

- Install all required packages:

.. code-block:: bash

    pip install --user setuptools pyserial click cryptography future pyparsing pyelftools

Building
--------

If you have all the dependencies met, it is time to build the libraries.

To build using the default configuration:

.. code-block:: bash

    ./build.sh

Custom Build
************

There are some options to help you create custom libraries. You can use the following options:

Usage
^^^^^

.. code-block:: bash

    build.sh [-s] [-A arduino_branch] [-I idf_branch] [-i idf_commit] [-c path] [-t <target>] [-b <build|menuconfig|idf_libs|copy_bootloader|mem_variant>] [config ...]

Skip Install/Update
^^^^^^^^^^^^^^^^^^^

Skip installing/updating of ESP-IDF and all components

.. code-block:: bash

    ./build.sh -s

This option can be used if you already have the ESP-IDF and all components already in your environment.

Set Arduino-ESP32 Branch
^^^^^^^^^^^^^^^^^^^^^^^^

Set which branch of arduino-esp32 to be used for compilation

.. code-block:: bash

    ./build.sh -A <arduino_branch>

Set ESP-IDF Branch
^^^^^^^^^^^^^^^^^^

Set which branch of ESP-IDF is to be used for compilation

.. code-block:: bash

    ./build.sh -I <idf_branch>

Set the ESP-IDF Commit
^^^^^^^^^^^^^^^^^^^^^^

Set which commit of ESP-IDF to be used for compilation

.. code-block:: bash

    ./build.sh -i <idf_commit>

Deploy
^^^^^^

Deploy the build to github arduino-esp32

.. code-block:: bash

    ./build.sh -d

Set the Arduino-ESP32 Destination Folder
^^^^^^^^^^^^^^^^^^^^^^^^^^^^^^^^^^^^^^^^

Set the arduino-esp32 folder to copy the result to. ex. '$HOME/Arduino/hardware/espressif/esp32'

.. code-block:: bash

    ./build.sh -c <path>

This function is used to copy the compiled libraries to the Arduino folder.

Set the Target
^^^^^^^^^^^^^^

Set the build target(chip). ex. 'esp32s3'

.. code-block:: bash

    ./build.sh -t <target>

This build command will build for the ESP32-S3 target. You can specify other targets.

* esp32
* esp32s2
* esp32c3
* esp32s3

Set Build Type
^^^^^^^^^^^^^^

Set the build type. ex. 'build' to build the project and prepare for uploading to a board.

.. note:: This command depends on the ``-t`` argument.

.. code-block:: bash

    ./build.sh -t esp32 -b <build|menuconfig|idf_libs|copy_bootloader|mem_variant>

Additional Configuration
^^^^^^^^^^^^^^^^^^^^^^^^

Specify additional configs to be applied. ex. 'qio 80m' to compile for QIO Flash@80MHz. Requires -b

.. note:: This command requires the ``-b`` to work properly.

.. code-block:: bash

    ./build.sh -t esp32 -b idf_libs qio 80m

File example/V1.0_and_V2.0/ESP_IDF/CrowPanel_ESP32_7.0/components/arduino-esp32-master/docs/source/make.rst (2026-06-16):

==============
makeEspArduino
==============

The `makeEspArduino <https://github.com/plerup/makeEspArduino>`_ is a generic makefile for any ESP8266/ESP32 Arduino project. 
Using it instead of the Arduino IDE makes it easier to do automated and production builds.

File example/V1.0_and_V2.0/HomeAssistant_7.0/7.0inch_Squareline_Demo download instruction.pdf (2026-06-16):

# 7.0inch_Squareline_Demo Download Introduction

## 1. Operation before downloading cases

(1) Place all the lib library files provided in the folder into the libraries file of the

arduino.

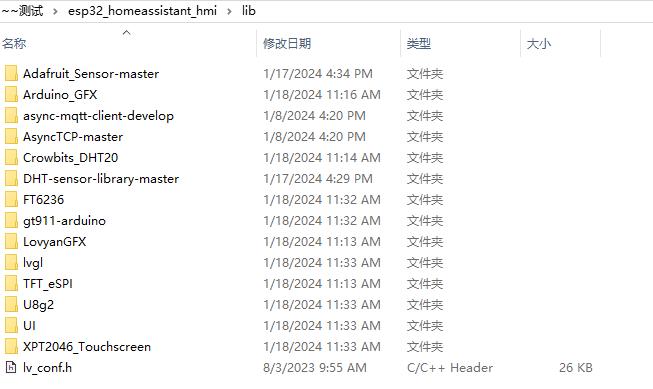
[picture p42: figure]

## Sensor wiring:

(1) Temperature and humidity sensor (Crowtail-DHT20-V1.0) with IIC interface

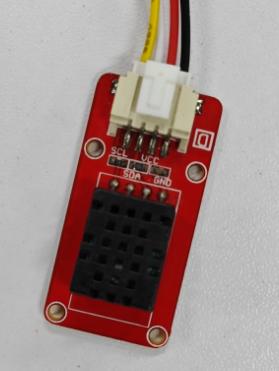
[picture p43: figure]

(2) LED to IO38 port

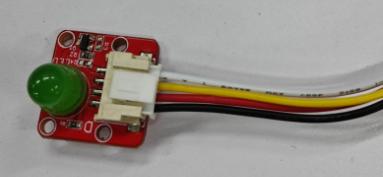
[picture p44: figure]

2. Use | arduino | software | to | open

## 7.0inch_Squareline_Demo.ino, arduino related operations

## can refer to this screen wiki

（https://www.elecrow.com/wiki/index.php?title=ESP32_Display_7.0%27%27_Intelli

gent_Touch_Screen_Wi-Fi%26BLE_800*480_HMI_Display）

## Download Settings:

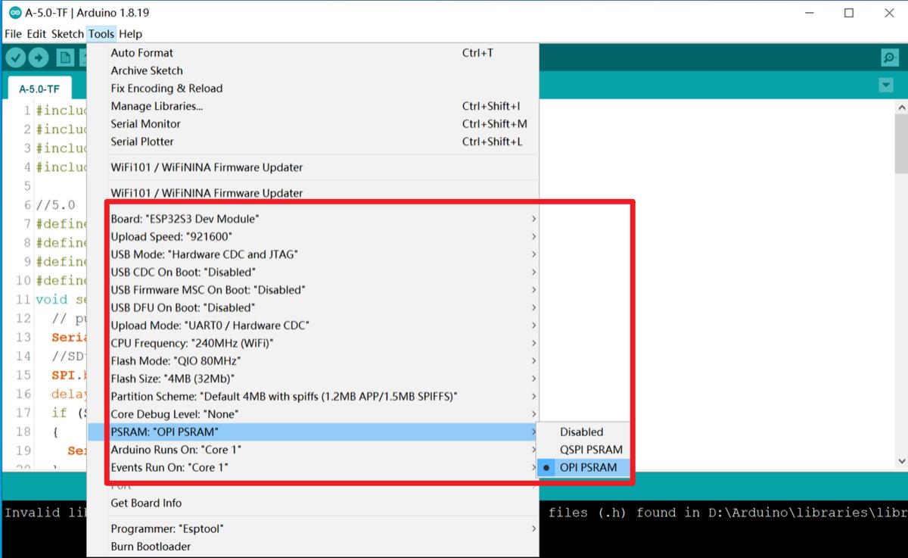
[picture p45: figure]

3. Download the programme.

4. Operational effects.

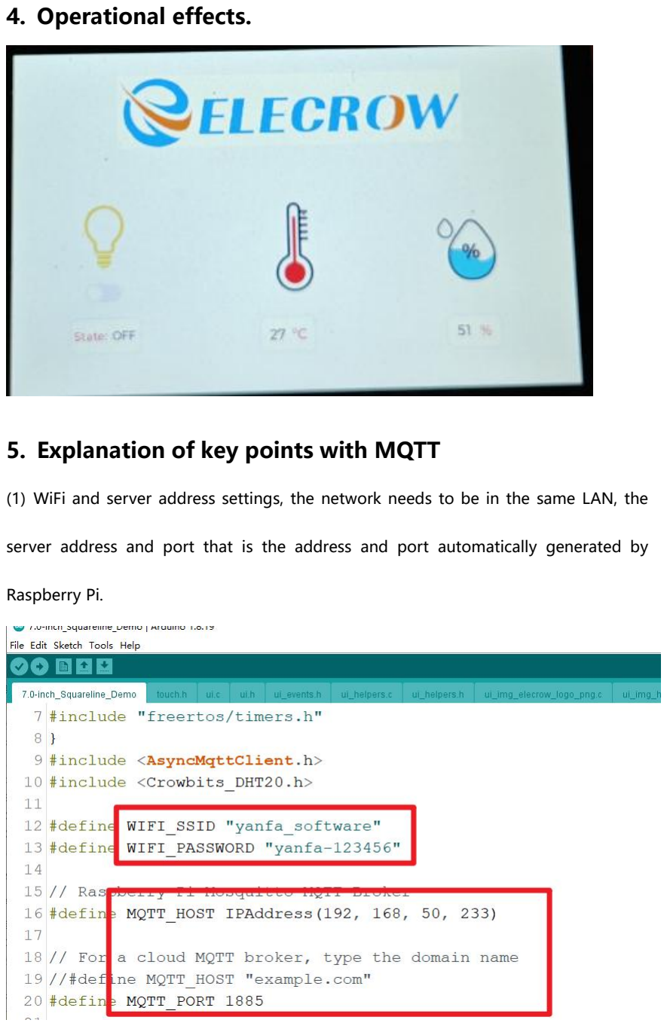
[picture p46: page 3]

## 5. Explanation of key points with MQTT

(1) WiFi and server address settings, the network needs to be in the same LAN, the

server address and port that is the address and port automatically generated by

Raspberry Pi.

(2) MQTT theme settings, the specific parameters are set according to the contents of

the configuration.yaml file on the MQTT server.

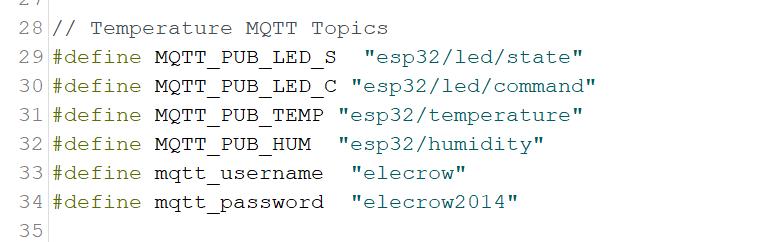
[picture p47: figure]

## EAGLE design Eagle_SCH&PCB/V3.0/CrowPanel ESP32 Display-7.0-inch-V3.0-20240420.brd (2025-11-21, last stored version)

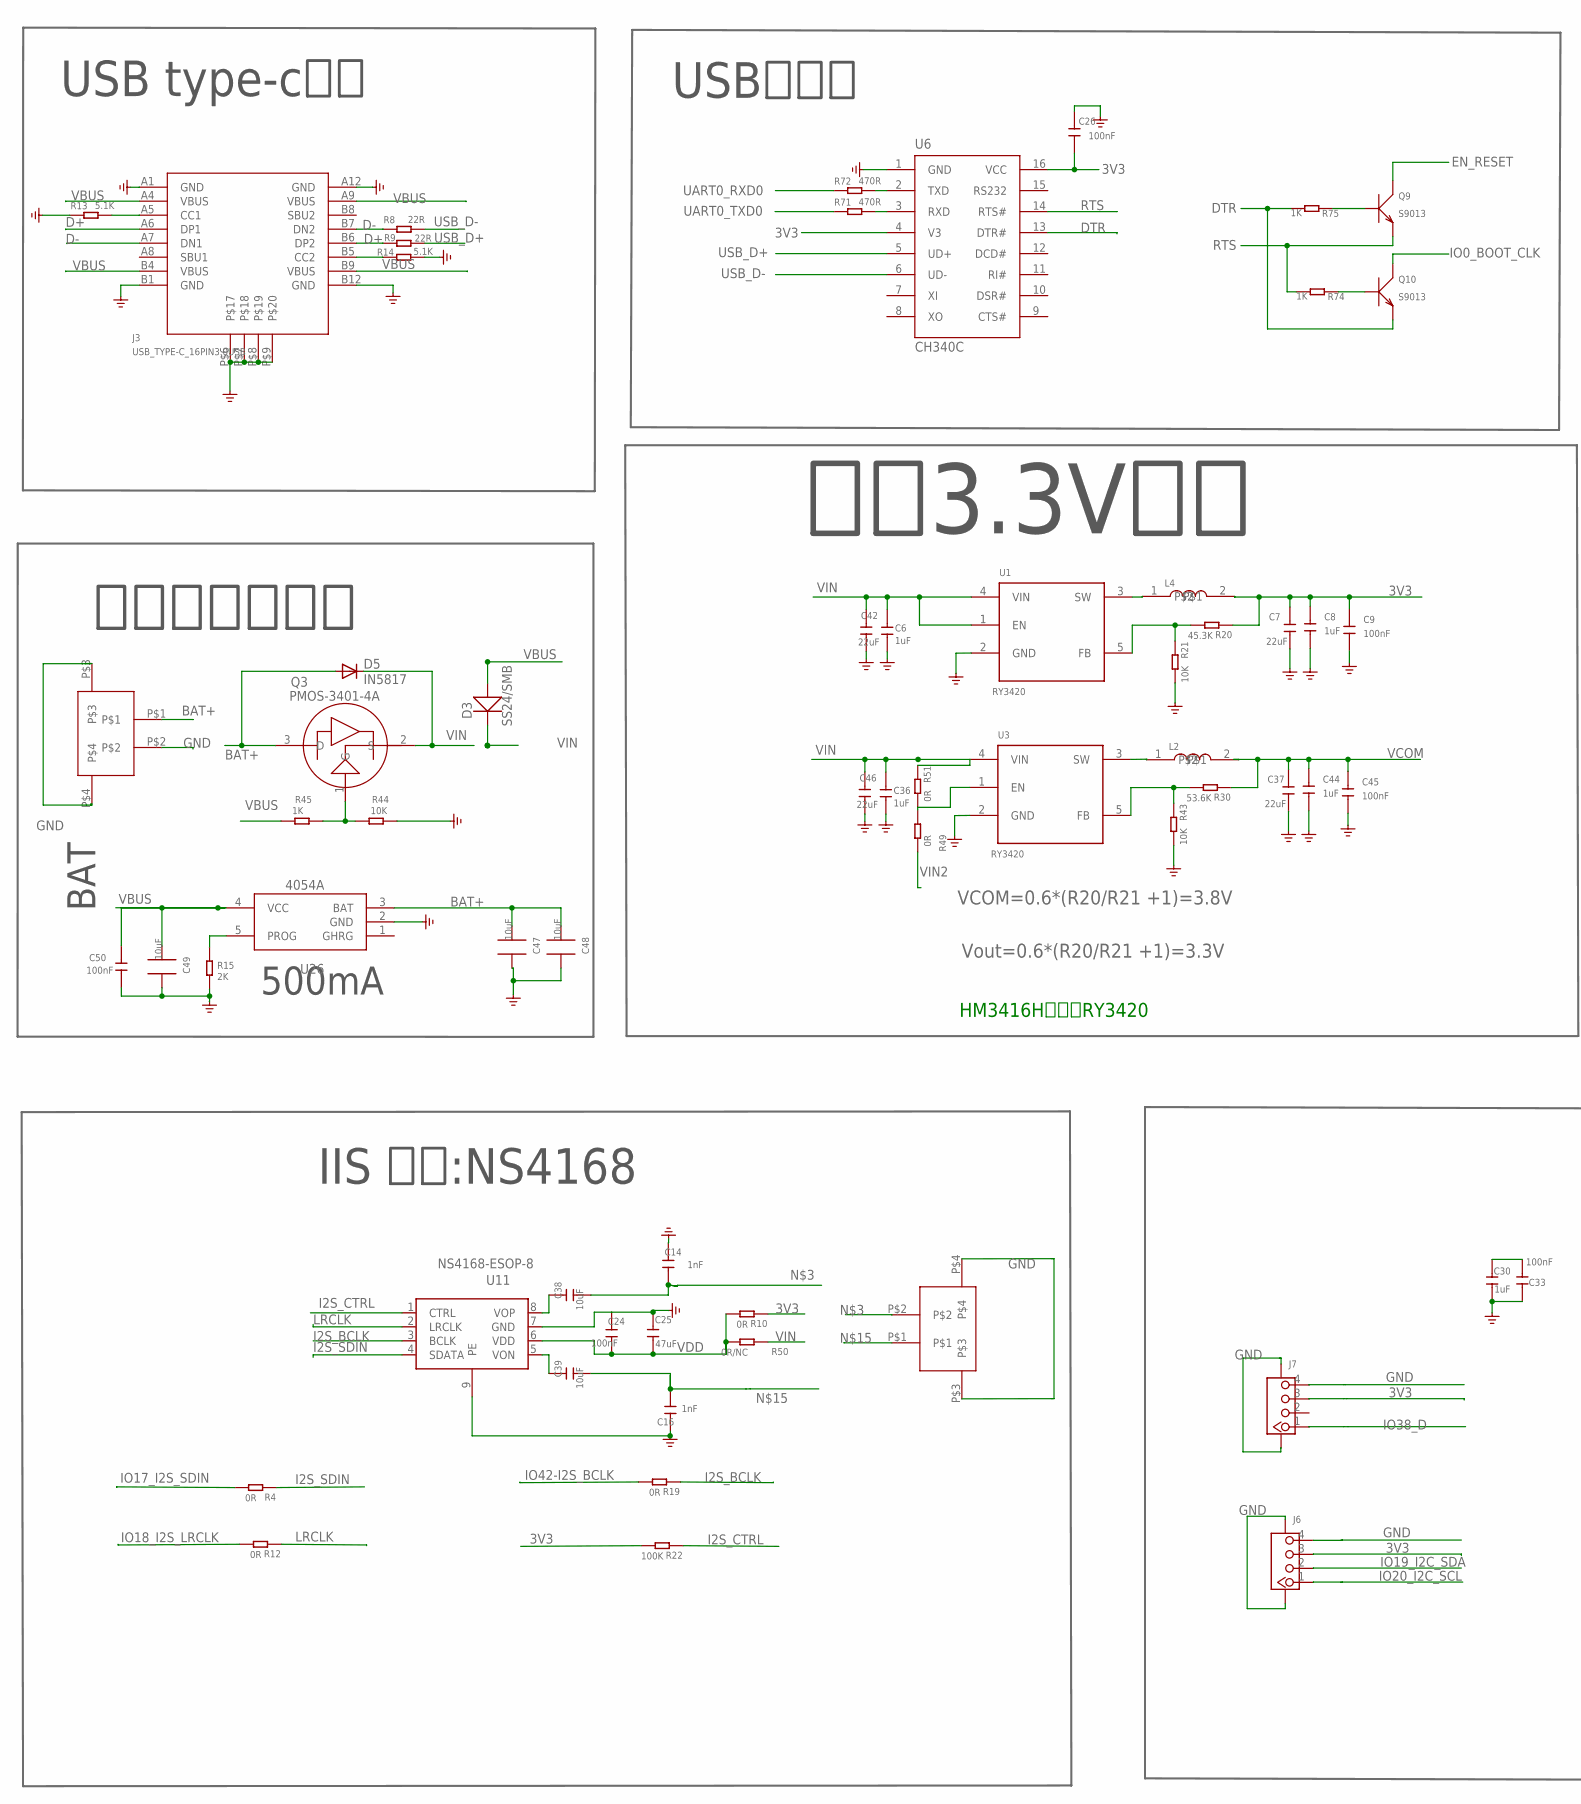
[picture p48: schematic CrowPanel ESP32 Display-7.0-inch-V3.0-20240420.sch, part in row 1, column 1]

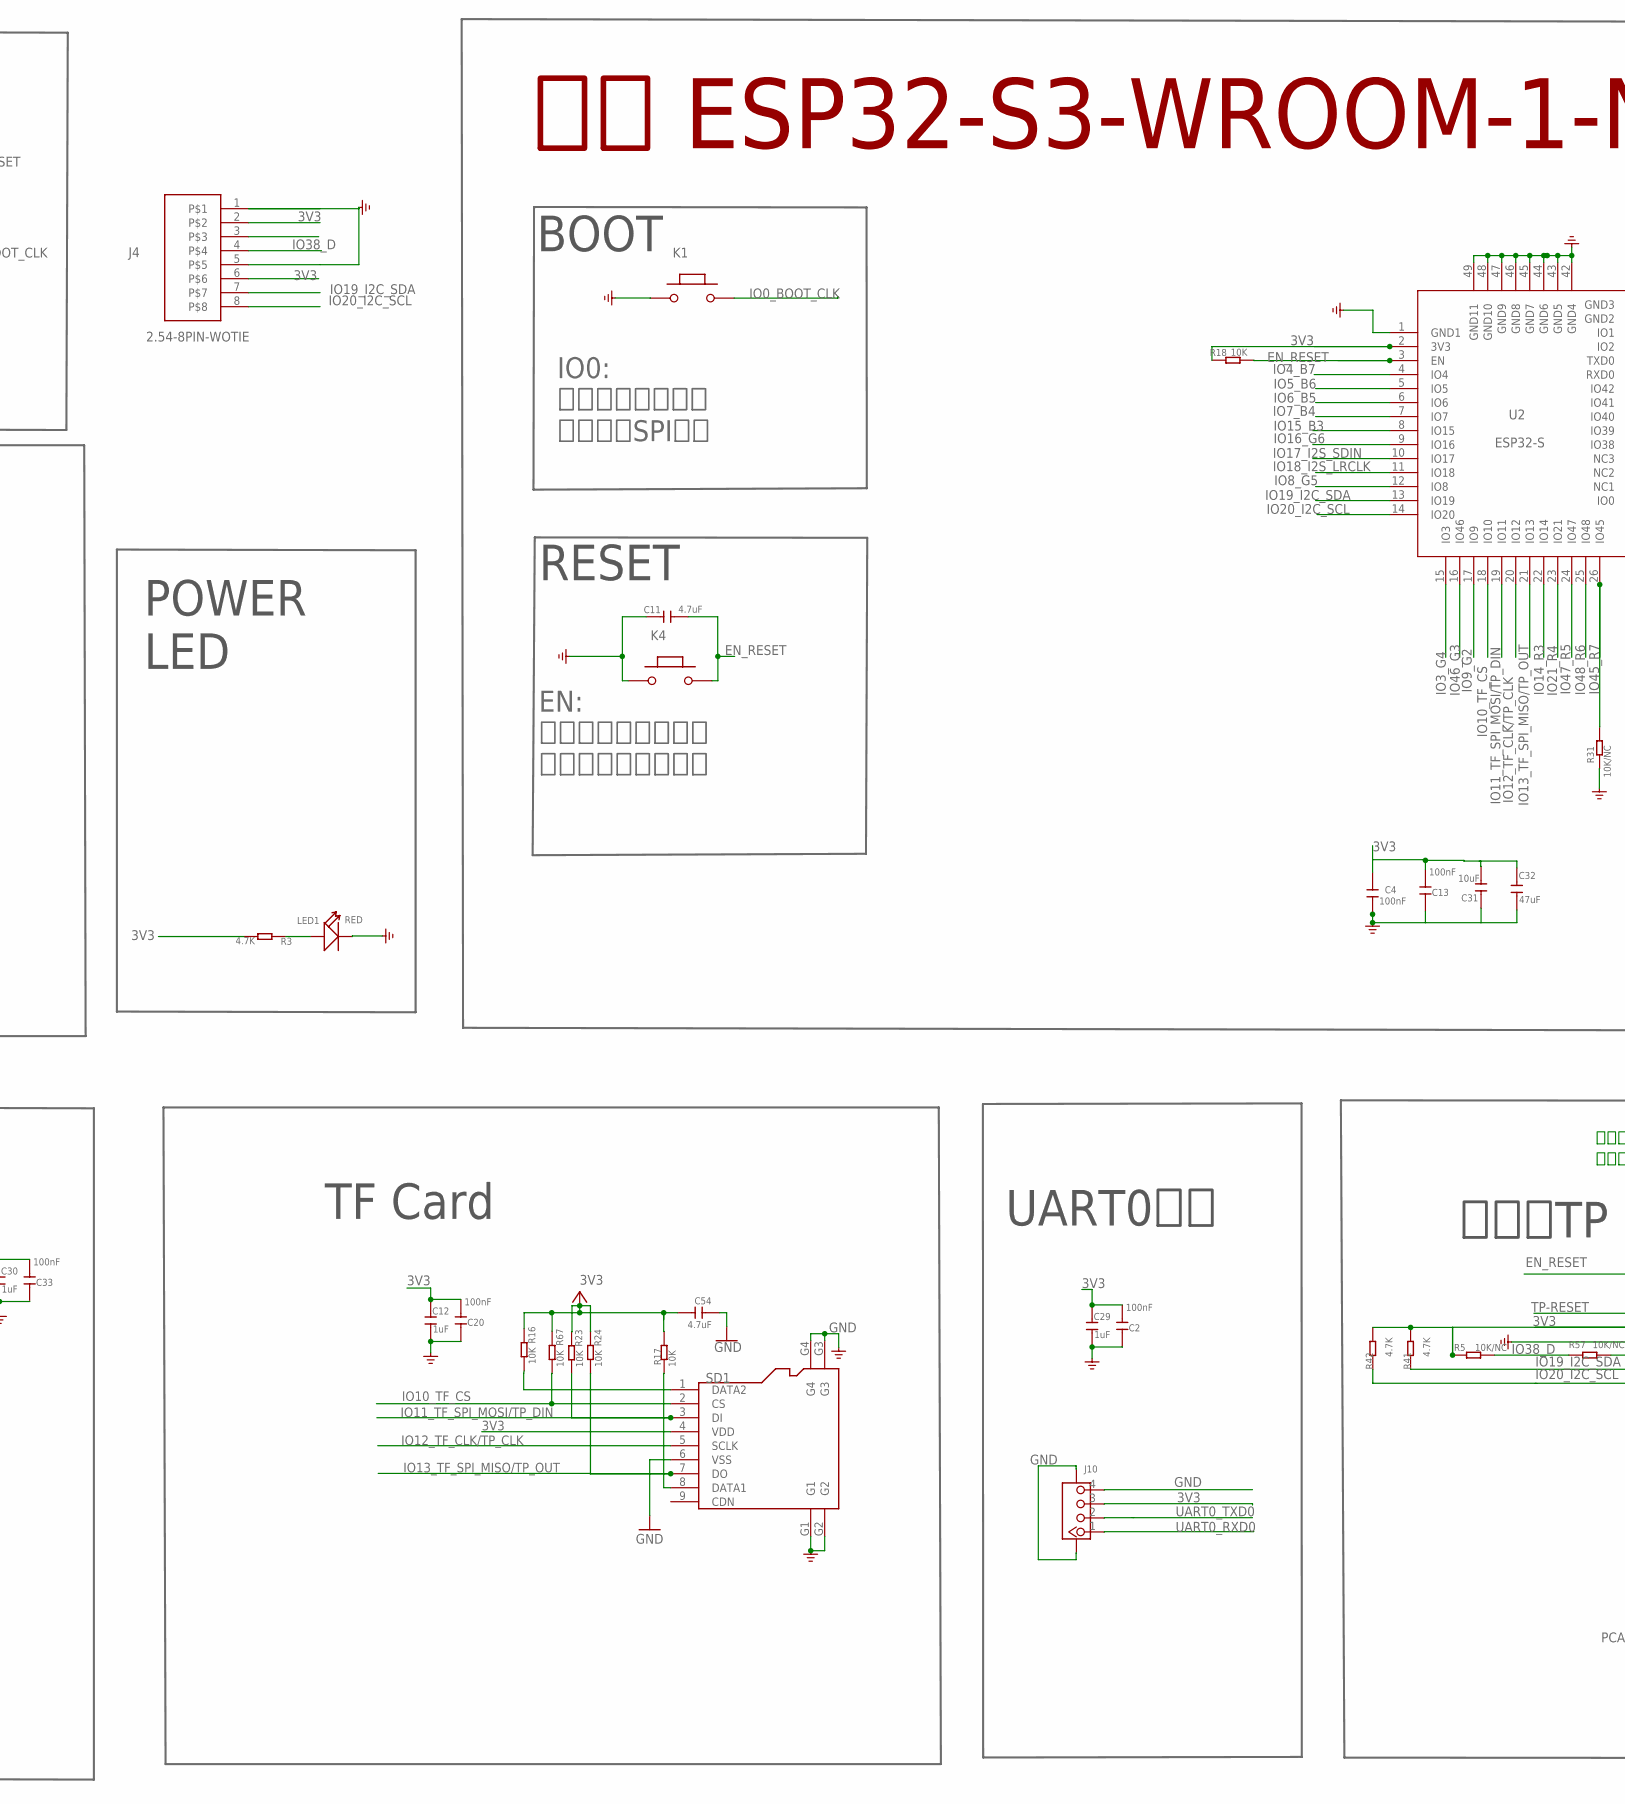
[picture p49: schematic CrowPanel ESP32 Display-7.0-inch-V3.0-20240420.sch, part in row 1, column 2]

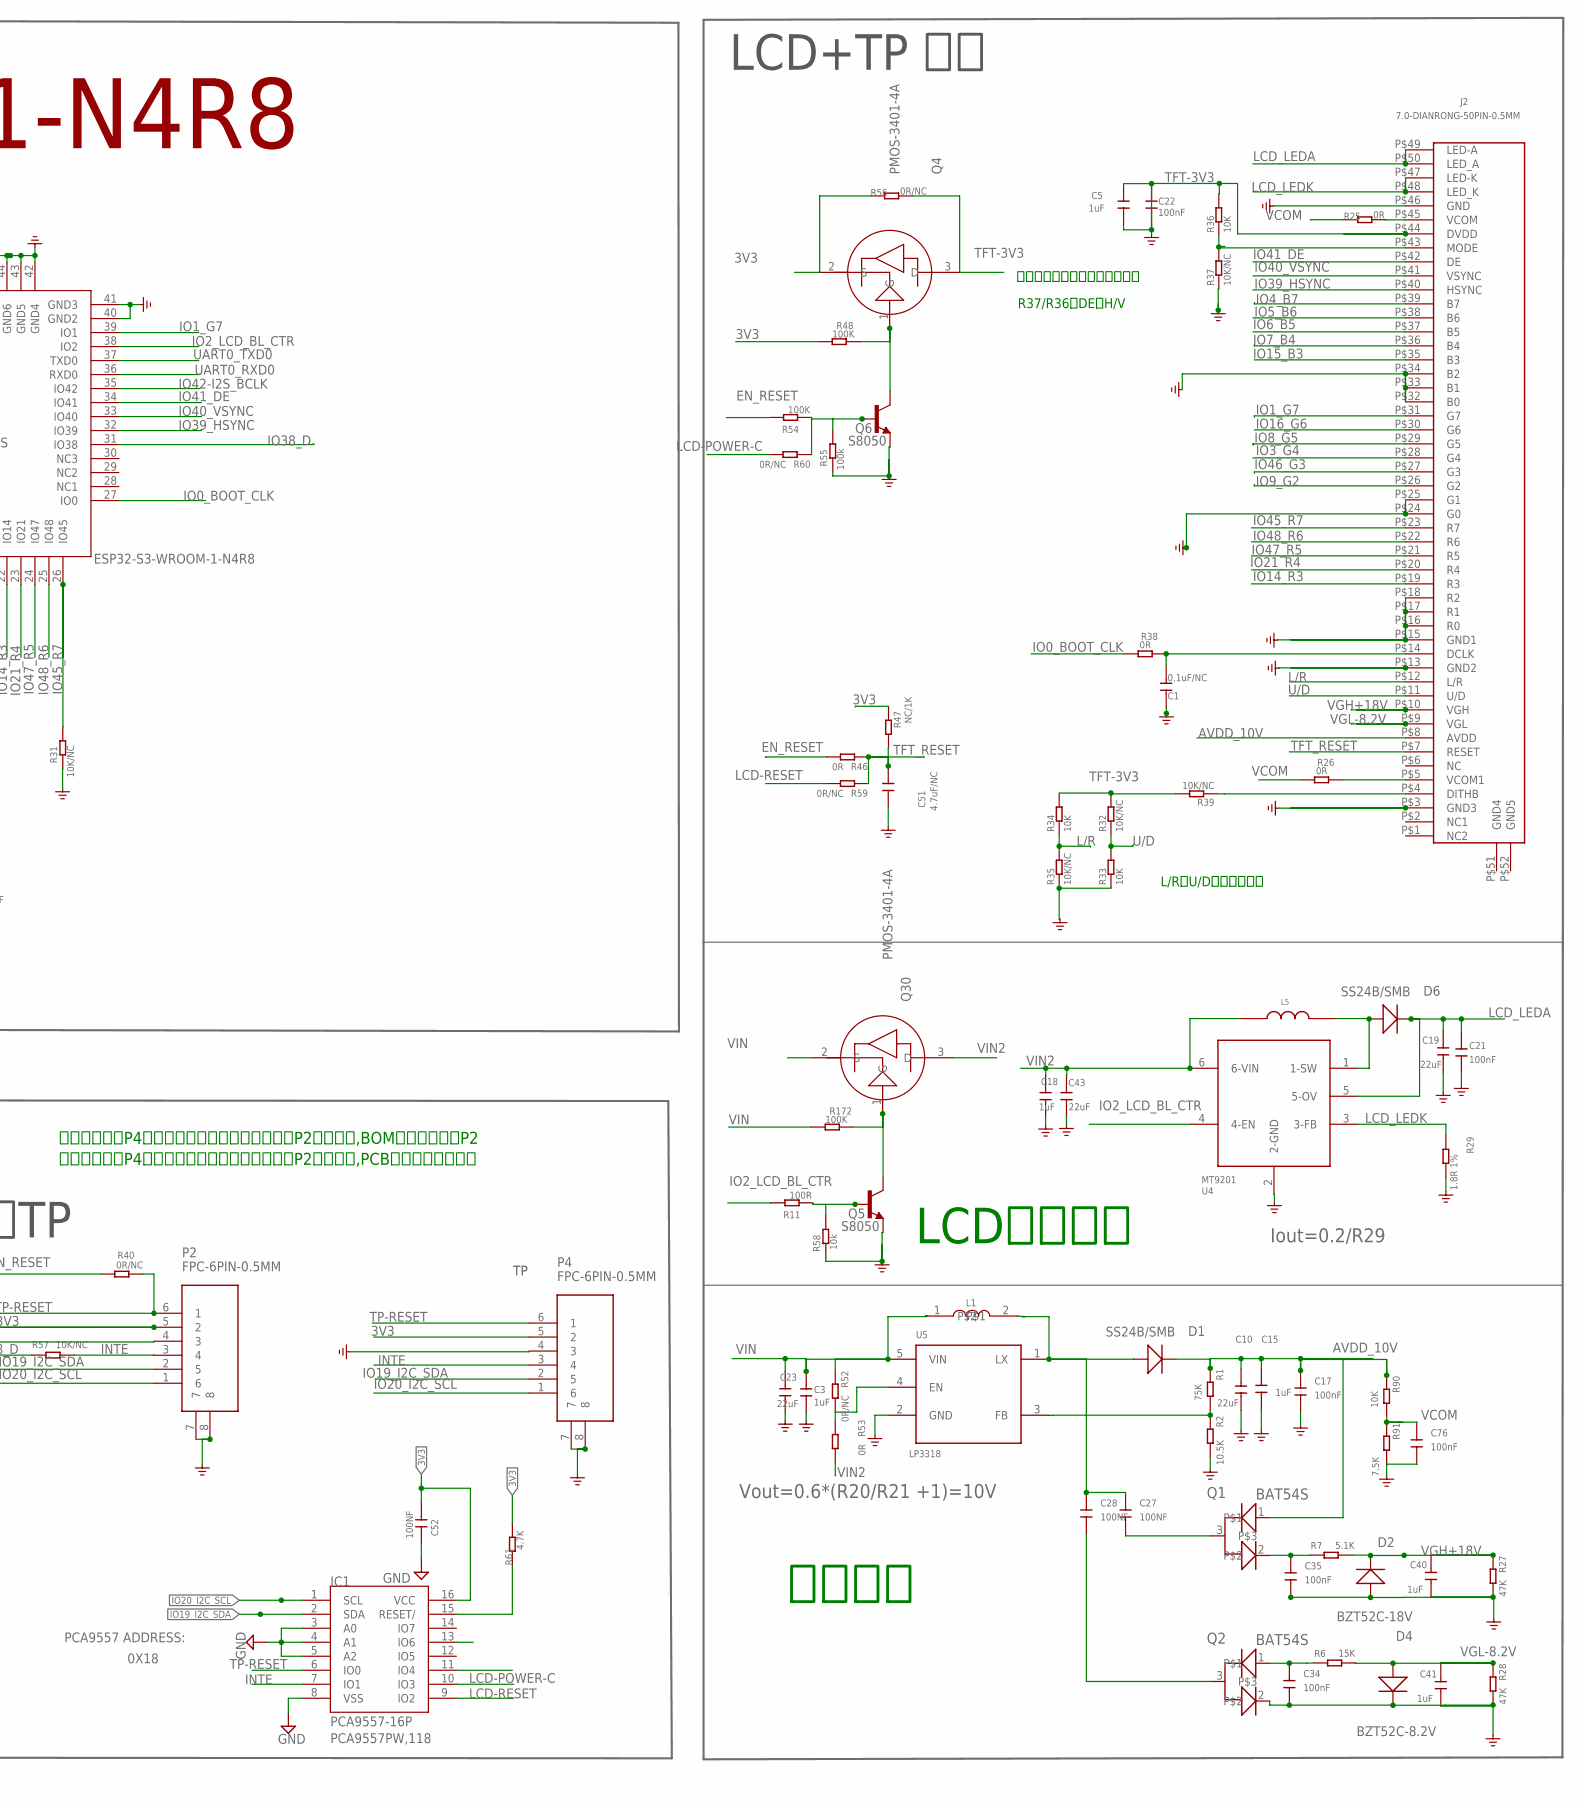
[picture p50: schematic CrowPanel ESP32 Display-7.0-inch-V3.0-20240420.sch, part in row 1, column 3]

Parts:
C1: 0.1uF/NC; DISCRETE_C0603
C2, C4, C13, C20, C22, C24, C33, C50: 100nF; C0603
C3, C6, C8, C15, C18, C36, C44: 1uF; 0603
C5: 1uF; C0603
C7, C10, C19, C23, C37, C42, C43, C46: 22uF; 0805
C9, C17, C21, C26, C34, C35, C45, C76: 100nF; 0603
C11: 4.7uF; 0603
C12, C29, C30: 1uF; DISCRETE_C0603
C14, C16: 1nF; C0603
C25, C32: 47uF; 0805
C27, C28: 100NF; 0603
C31: 10uF; DISCRETE_C0603
C38, C39: 10uF; C0603
C40, C41: 1uF; 0805
C47, C48, C49: 10uF; 0805_S
C51: 4.7uF/NC; 0603
C52: 100NF; A_XBJ_0603
C54: 4.7uF; DISCRETE_C0603
D1, D6: SS24B/SMB; 214AB
D2: BZT52C-18V; DISCRETE_SOD123
D3: SS24/SMB; 214AB
D4: BZT52C-8.2V; DISCRETE_SOD123
D5: IN5817; DO-214AC
IC1: PCA9557-16P; TSSOP16
J1, J5: PH2.0WT-2PIN
J2: 7.0-DIANRONG-50PIN-0.5MM; 7.0-DAINRONG-50PIN-0.5MM
J3: USB_TYPE-C_16PIN3.0USB; KEVIN_3.0TYPEC-SMD
J4: 2.54-8PIN-WOTIE; 2.54-8P-WOTIE
J6, J7, J10: CONNECTOR_TWIG-4P-2.0-SMD-FEMALE-REINFORCE90D; CONNECTOR_4P-SMD-2.0-90D
K1, K4: BUTTON; 157SW
L1, L2, L4: L-0530; CD54_CD54
L5: CD32_6.8uH; CD32
LED1: RED; DISCRETE_LED-0603
P2, P4: FPC-6PIN-0.5MM
Q1, Q2: BAT54S; SOT23-3
Q3, Q4, Q30: PMOS-3401-4A; SOT-23
Q5, Q6: S8050; SPARKFUN_SOT23
Q9, Q10: S9013; SOT23@1
R1: 75K; DISCRETE_R0603
R2: 10.5K; DISCRETE_R0603
R3, R41, R42, R61: 4.7K; DISCRETE_R0603
R4, R10, R12, R19, R25, R46, R49, R51, R53: 0R; DISCRETE_R0603
R5, R32, R35, R37, R39, R57: 10K/NC; DISCRETE_R0603
R6: 15K; DISCRETE_R0603
R7, R13, R14: 5.1K; DISCRETE_R0603
R8, R9: 22R; DISCRETE_R0603
R11: 100R; R0603
R15: 2K; DISCRETE_R0603
R16, R17, R18, R21, R23, R24, R33, R34, R36, R43, R44, R67, R90: 10K; DISCRETE_R0603
R20: 45.3K; DISCRETE_R0603
R22: 100K; DISCRETE_R0603
R26, R38: 0R; R0603
R27, R28: 47K; DISCRETE_R0603
R29: 1.8R 1%; DISCRETE_R0603
R30: 53.6K; DISCRETE_R0603
R31: 10K/NC; R0603
R40: 0R/NC; R0603
R45, R74, R75: 1K; DISCRETE_R0603
R47: NC/1K; DISCRETE_R0603
R48, R54, R172: 100K; R0603
R50, R52, R56, R59, R60: 0R/NC; DISCRETE_R0603
R55: 100k; R0603
R58: 10k; R0603
R71, R72: 470R; DISCRETE_R0603
R91: 7.5K; DISCRETE_R0603
SD1: HOLDER-MICROSD-9P; 9P-SMD-W/-RING
U1, U3: RY3420; A_XBJ_SOT23-5
U2: ESP32-S; ESP32-S3
U4: MT9201; SOT23-6
U5: LP3318; LP3318_SOT23-5
U6: CH340C; SOP-16
U11: NS4168-ESOP-8
U26: 4054A; SOP23-5

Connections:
3V3: C2.1, C4.2, C7.2, C8.2, C9.2, C12.2, C13.1, C20.1, C26.1, C29.2, C30.2, C31.2, C32.2, C33.1, C52.1, C54.2, IC1.16 (VCC), J4.2, J4.6, J6.3, J7.3, J10.3, L4.2, P2.5 (2), P4.5 (2), Q4.2 (S), R3.2, R5.1, R10.1, R16.1, R17.1, R18.1, R20.1, R22.2, R23.1, R24.1, R41.2, R42.2, R47.2, R48.1, R56.1, R61.2, R67.1, SD1.4 (VDD), U2.2 (3V3), U6.4 (V3), U6.16 (VCC)
AVDD_10V: C10.2, C15.2, C17.2, D1.2 (-), J2.P$8 (AVDD), Q1.1, R1.1, R90.1
BAT+: C47.2, C48.2, D5.A, J1.P$1, Q3.3 (D), U26.3 (BAT)
D+: J3.A6 (DP1), J3.B6 (DP2), R9.1
D-: J3.A7 (DN1), J3.B7 (DN2), R8.1
DCLK1: C1.2, J2.P$14 (DCLK), R38.2
DTR: Q10.2 (E), R75.2, U6.13 (DTR#)
EN_RESET: C11.1, K4.2, Q9.3 (C), R18.2, R40.1, R46.2, R54.2, U2.3 (EN)
GND: C1.1, C2.2, C3.1, C4.1, C5.2, C6.1, C7.1, C8.1, C9.1, C10.1, C11.2, C12.1, C13.2, C14.2, C15.1, C16.2, C17.1, C18.1, C19.1, C20.2, C21.1, C22.1, C23.1, C24.2, C25.2, C26.2, C29.1, C30.1, C31.1, C32.1, C33.2, C34.1, C35.1, C36.1, C37.1, C40.1, C41.1, C42.1, C43.1, C44.1, C45.1, C46.1, C47.1, C48.1, C49.1, C50.2, C51.2, C52.2, C54.1, C76.1, D2.+, D4.-, IC1.3 (A0), IC1.4 (A1), IC1.5 (A2), IC1.8 (VSS), J1.P$2, J1.P$3, J1.P$4, J2.P$3 (GND3), J2.P$13 (GND2), J2.P$15 (GND1), J2.P$16 (R0), J2.P$17 (R1), J2.P$18 (R2), J2.P$24 (G0), J2.P$25 (G1), J2.P$32 (B0), J2.P$33 (B1), J2.P$34 (B2), J2.P$46 (GND), J3.A1 (GND), J3.A12 (GND), J3.B1 (GND), J3.B12 (GND), J3.P$6, J3.P$7, J3.P$8, J3.P$9, J4.1, J4.5, J5.P$3, J5.P$4, J6.4, J6.SS1, J6.SS2, J7.4, J7.SS1, J7.SS2, J10.4, J10.SS1, J10.SS2, K1.1, K4.1, LED1.-, P2.4 (3), P2.7, P2.8, P4.4 (3), P4.7, P4.8, Q2.2, Q5.2 (E), Q6.2 (E), R2.2, R13.1, R14.2, R15.2, R21.2, R27.2, R28.2, R29.2, R31.1, R33.1, R35.1, R37.1, R43.2, R44.1, R55.1, R58.1, R91.2, SD1.6 (VSS), SD1.G1, SD1.G2, SD1.G3, SD1.G4, U1.2 (GND), U2.1 (GND1), U2.40 (GND2), U2.41 (GND3), U2.42 (GND4), U2.43 (GND5), U2.44 (GND6), U2.45 (GND7), U2.46 (GND8), U2.47 (GND9), U2.48 (GND10), U2.49 (GND11), U3.2 (GND), U4.2 (2-GND), U5.2 (GND), U6.1 (GND), U11.7 (GND), U11.9 (PE), U26.2 (GND)
I2S_BCLK: R19.1, U11.3 (BCLK)
I2S_CTRL: R22.1, U11.1 (CTRL)
I2S_SDIN: R4.1, U11.4 (SDATA)
INTE: IC1.7 (IO1), P2.3 (4), P4.3 (4), R57.2
IO0_BOOT_CLK: K1.2, Q10.3 (C), R38.1, U2.27 (IO0)
IO1_G7: J2.P$31 (G7), U2.39 (IO1)
IO2_LCD_BL_CTR: R11.2, U2.38 (IO2), U4.4 (4-EN)
IO3_G4: J2.P$28 (G4), U2.15 (IO3)
IO4_B7: J2.P$39 (B7), U2.4 (IO4)
IO5_B6: J2.P$38 (B6), U2.5 (IO5)
IO6_B5: J2.P$37 (B5), U2.6 (IO6)
IO7_B4: J2.P$36 (B4), U2.7 (IO7)
IO8_G5: J2.P$29 (G5), U2.12 (IO8)
IO9_G2: J2.P$26 (G2), U2.17 (IO9)
IO10_TF_CS: R67.2, SD1.2 (CS), U2.18 (IO10)
IO11_TF_SPI_MOSI/TP_DIN: R23.2, SD1.3 (DI), U2.19 (IO11)
IO12_TF_CLK/TP_CLK: SD1.5 (SCLK), U2.20 (IO12)
IO13_TF_SPI_MISO/TP_OUT: R24.2, SD1.7 (DO), U2.21 (IO13)
IO14_R3: J2.P$19 (R3), U2.22 (IO14)
IO15_B3: J2.P$35 (B3), U2.8 (IO15)
IO16_G6: J2.P$30 (G6), U2.9 (IO16)
IO17_I2S_SDIN: R4.2, U2.10 (IO17)
IO18_I2S_LRCLK: R12.2, U2.11 (IO18)
IO19_I2C_SDA: IC1.2 (SDA), J4.7, J6.2, P2.2 (5), P4.2 (5), R41.1, U2.13 (IO19)
IO20_I2C_SCL: IC1.1 (SCL), J4.8, J6.1, P2.1 (6), P4.1 (6), R42.1, U2.14 (IO20)
IO21_R4: J2.P$20 (R4), U2.23 (IO21)
IO38_D: J4.4, J7.1, R5.2, R57.1, U2.31 (IO38)
IO39_HSYNC: J2.P$40 (HSYNC), U2.32 (IO39)
IO40_VSYNC: J2.P$41 (VSYNC), U2.33 (IO40)
IO41_DE: J2.P$42 (DE), U2.34 (IO41)
IO42-I2S_BCLK: R19.2, U2.35 (IO42)
IO45_R7: J2.P$23 (R7), R31.2, U2.26 (IO45)
IO46_G3: J2.P$27 (G3), U2.16 (IO46)
IO47_R5: J2.P$21 (R5), U2.24 (IO47)
IO48_R6: J2.P$22 (R6), U2.25 (IO48)
L/R: J2.P$12 (L/R), R34.1, R35.2
LCD-POWER-C: IC1.10 (IO3), R60.2
LCD-RESET: IC1.9 (IO2), R59.2
LCD_LEDA: C19.2, C21.2, D6.2 (-), J2.P$49 (LED-A), J2.P$50 (LED_A), U4.5 (5-OV)
LCD_LEDK: J2.P$47 (LED-K), J2.P$48 (LED_K), R29.1, U4.3 (3-FB)
LRCLK: R12.1, U11.2 (LRCLK)
unnamed: LED1.+, R3.1
unnamed: J2.P$45 (VCOM), R25.2
unnamed: C14.1, C38.1, J5.P$2
unnamed: J2.P$5 (VCOM1), R26.2
unnamed: C38.2, U11.8 (VOP)
unnamed: R1.2, R2.1, U5.3 (FB)
unnamed: C39.2, U11.5 (VON)
unnamed: C27.2, C28.2, D1.1 (+), L1.2, U5.1 (LX)
unnamed: C27.1, Q1.3
unnamed: J3.A5 (CC1), R13.2
unnamed: J2.P$43 (MODE), R36.1, R37.2
unnamed: L4.1, U1.3 (SW)
unnamed: J2.P$4 (DITHB), R39.1
unnamed: C16.1, C39.1, J5.P$1
unnamed: D6.1 (+), L5.2, U4.1 (1-SW)
unnamed: J3.B5 (CC2), R14.1
unnamed: R30.2, R43.1, U3.5 (FB)
unnamed: L2.1, U3.3 (SW)
unnamed: R20.2, R21.1, U1.5 (FB)
unnamed: Q3.1 (G), R44.2, R45.1
unnamed: R15.1, U26.5 (PROG)
unnamed: Q5.1 (B), R11.1, R58.2
unnamed: C28.1, Q2.3
unnamed: R49.1, R51.2, U3.1 (EN)
unnamed: Q4.1 (G), Q6.3 (C), R48.2
unnamed: C35.2, Q1.2, R7.1
unnamed: C34.2, Q2.1, R6.1
unnamed: R52.2, R53.1, U5.4 (EN)
unnamed: Q9.1 (B), R75.1
unnamed: Q6.1 (B), R54.1, R55.2, R60.1
unnamed: Q5.3 (C), Q30.1 (G), R172.2
unnamed: Q10.1 (B), R74.1
unnamed: R72.2, U6.2 (TXD)
unnamed: R71.2, U6.3 (RXD)
unnamed: R16.2, SD1.1 (DATA2)
unnamed: R17.2, SD1.8 (DATA1)
unnamed: IC1.15 (RESET/), R61.1
RTS: Q9.2 (E), R74.2, U6.14 (RTS#)
TFT-3V3: C5.1, C22.2, J2.P$44 (DVDD), Q4.3 (D), R32.2, R34.2, R36.2, R39.2, R56.2
TFT_RESET: C51.1, J2.P$7 (RESET), R46.1, R47.1, R59.1
TP-RESET: IC1.6 (IO0), P2.6 (1), P4.6 (1), R40.2
U/D: J2.P$11 (U/D), R32.1, R33.2
UART0_RXD0: J10.1, R72.1, U2.36 (RXD0)
UART0_TXD0: J10.2, R71.1, U2.37 (TXD0)
USB_D+: R9.2, U6.5 (UD+)
USB_D-: R8.2, U6.6 (UD-)
VBUS: C49.2, C50.1, D3.1 (+), J3.A4 (VBUS), J3.A9 (VBUS), J3.B4 (VBUS), J3.B9 (VBUS), R45.2, U26.4 (VCC)
VCOM: C37.2, C44.2, C45.2, C76.2, L2.2, R25.1, R26.1, R30.1, R90.2, R91.1
VDD: C24.1, C25.1, R10.2, R50.2, U11.6 (VDD)
VGH+18V: C40.2, D2.-, J2.P$10 (VGH), R7.2, R27.1
VGL-8.2V: C41.2, D4.+, J2.P$9 (VGL), R6.2, R28.1
VIN: C3.2, C6.2, C23.2, C36.2, C42.2, C46.2, D3.2 (-), D5.C, L1.1, Q3.2 (S), Q30.2 (S), R50.1, R51.1, R52.1, R172.1, U1.1 (EN), U1.4 (VIN), U3.4 (VIN), U5.5 (VIN)
VIN2: C18.2, C43.2, L5.1, Q30.3 (D), R49.2, R53.2, U4.6 (6-VIN)

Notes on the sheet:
Vout=0.6*(R20/R21 +1)=3.3V
系统3.3V电源
UART0接口
主控 ESP32-S3-WROOM-1-N4R8
USB type-c座子
电池及控制电路
IO0: 低电平：下载启动 高电平：SPI启动
EN: 高电平：芯片使能； 低电平：芯片关闭。
USB转串口
IIS 功放:NS4168
TF Card
BOOT
RESET
POWER LED
LCD+TP 接口
电容屏TP
Iout=0.2/R29
L/R和U/D，预留上下拉
数据传输模式选择，预留上下拉
R37/R36选DE和H/V
Vout=0.6*(R20/R21 +1)=10V
正负压源
LCD恒流驱动
默认使用右边P4的触摸接口，如需更换使用左边P2触摸接口,BOM需要更改使用P2
默认使用右边P4的触摸接口，如需更换使用左边P2触摸接口,PCB的排线孔也要更改
HM3416H更换为RY3420
VCOM=0.6*(R20/R21 +1)=3.8V
500mA
BAT
PCA9557 ADDRESS:
0X18
PCA9557PW,118

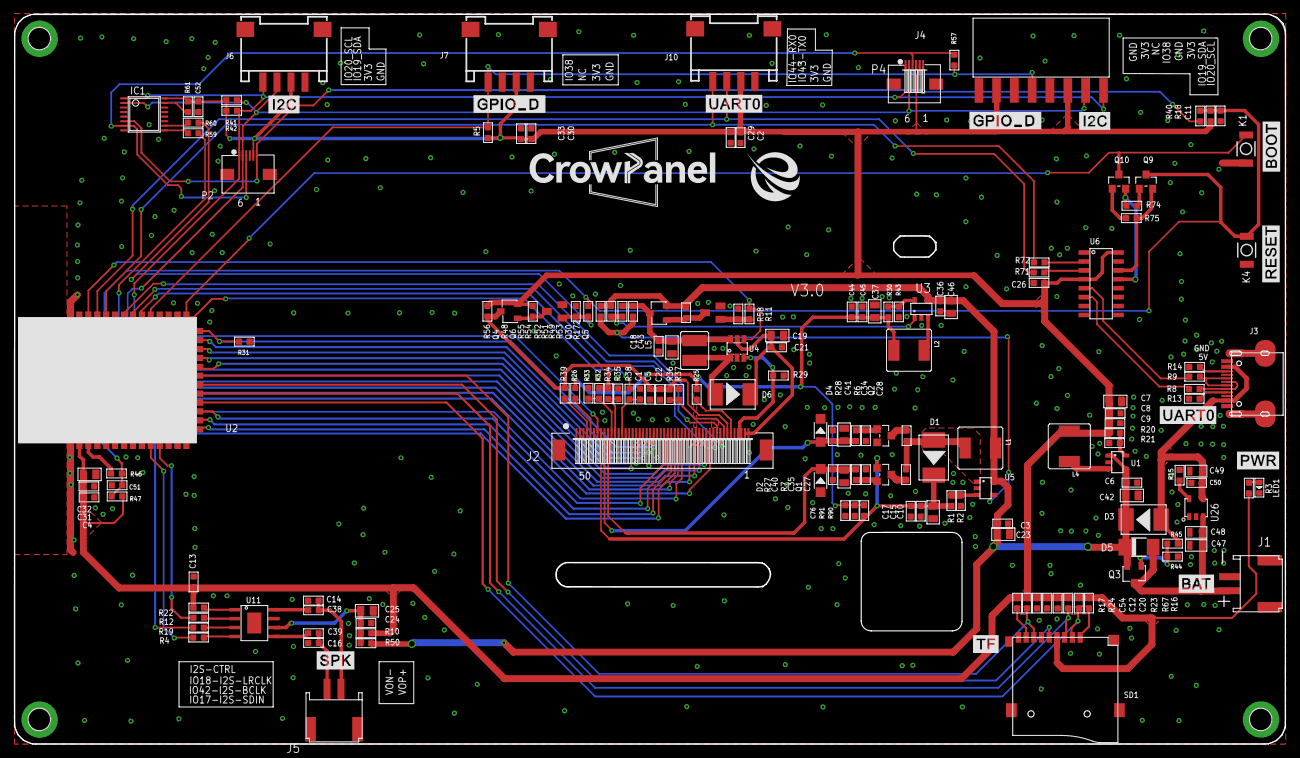
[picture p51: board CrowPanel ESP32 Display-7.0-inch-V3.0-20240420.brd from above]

Board: 2 copper layers, 181.1 x 103.9 mm, 169 parts (1 on the bottom side), 103 nets.

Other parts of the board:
U$10: 7.0底框
U$15: 7.0板框
U$76: LOGE-2.0
U$78: LOGLE

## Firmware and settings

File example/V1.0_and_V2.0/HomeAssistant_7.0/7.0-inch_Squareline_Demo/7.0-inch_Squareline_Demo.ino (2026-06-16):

#include <Wire.h>
#include <SPI.h>
#include <WiFi.h>

extern "C" {
#include "freertos/FreeRTOS.h"
#include "freertos/timers.h"
}
#include <AsyncMqttClient.h>
#include <Crowbits_DHT20.h>

#define WIFI_SSID "yanfa_software"
#define WIFI_PASSWORD "yanfa-123456"

// Raspberry Pi Mosquitto MQTT Broker
#define MQTT_HOST IPAddress(192, 168, 50, 233)

// For a cloud MQTT broker, type the domain name
//#define MQTT_HOST "example.com"
#define MQTT_PORT 1885

// Temperature MQTT Topics
#define MQTT_PUB_LED_S  "esp32/led/state"
#define MQTT_PUB_LED_C "esp32/led/command"
#define MQTT_PUB_TEMP "esp32/temperature"
#define MQTT_PUB_HUM  "esp32/humidity"
#define mqtt_username  "elecrow"
#define mqtt_password  "elecrow2014"

// Initialize DHT20 sensor
Crowbits_DHT20 dht20;
int LED = 38;
AsyncMqttClient mqttClient;
TimerHandle_t mqttReconnectTimer;
TimerHandle_t wifiReconnectTimer;

#define USE_UI    //if you want to use the ui export from Squareline, please do not annotate this line.

#if defined USE_UI
#include <lvgl.h>
#include "ui.h"
#endif

#include <Arduino_GFX_Library.h>
#define TFT_BL 2
#define LGFX_USE_V1
#include <LovyanGFX.hpp>
#include <lgfx/v1/platforms/esp32s3/Panel_RGB.hpp>
#include <lgfx/v1/platforms/esp32s3/Bus_RGB.hpp>
class LGFX : public lgfx::LGFX_Device
{
  public:
    lgfx::Bus_RGB     _bus_instance;
    lgfx::Panel_RGB   _panel_instance;
    LGFX(void)
    {
      {
        auto cfg = _bus_instance.config();
        cfg.panel = &_panel_instance;

        cfg.pin_d0  = GPIO_NUM_15; // B0
        cfg.pin_d1  = GPIO_NUM_7;  // B1
        cfg.pin_d2  = GPIO_NUM_6;  // B2
        cfg.pin_d3  = GPIO_NUM_5;  // B3
        cfg.pin_d4  = GPIO_NUM_4;  // B4

        cfg.pin_d5  = GPIO_NUM_9;  // G0
        cfg.pin_d6  = GPIO_NUM_46; // G1
        cfg.pin_d7  = GPIO_NUM_3;  // G2
        cfg.pin_d8  = GPIO_NUM_8;  // G3
        cfg.pin_d9  = GPIO_NUM_16; // G4
        cfg.pin_d10 = GPIO_NUM_1;  // G5

        cfg.pin_d11 = GPIO_NUM_14; // R0
        cfg.pin_d12 = GPIO_NUM_21; // R1
        cfg.pin_d13 = GPIO_NUM_47; // R2
        cfg.pin_d14 = GPIO_NUM_48; // R3
        cfg.pin_d15 = GPIO_NUM_45; // R4

        cfg.pin_henable = GPIO_NUM_41;
        cfg.pin_vsync   = GPIO_NUM_40;
        cfg.pin_hsync   = GPIO_NUM_39;
        cfg.pin_pclk    = GPIO_NUM_0;
        cfg.freq_write  = 15000000;

        cfg.hsync_polarity    = 0;
        cfg.hsync_front_porch = 40;
        cfg.hsync_pulse_width = 48;
        cfg.hsync_back_porch  = 40;

        cfg.vsync_polarity    = 0;
        cfg.vsync_front_porch = 1;
        cfg.vsync_pulse_width = 31;
        cfg.vsync_back_porch  = 13;

        cfg.pclk_active_neg   = 1;
        cfg.de_idle_high      = 0;
        cfg.pclk_idle_high    = 0;

        _bus_instance.config(cfg);
      }
      {
        auto cfg = _panel_instance.config();
        cfg.memory_width  = 800;
        cfg.memory_height = 480;
        cfg.panel_width  = 800;
        cfg.panel_height = 480;
        cfg.offset_x = 0;
        cfg.offset_y = 0;
        _panel_instance.config(cfg);
      }
      _panel_instance.setBus(&_bus_instance);
      setPanel(&_panel_instance);
    }
};


LGFX lcd;

/*******************************************************************************
   Screen Driver Configuration  end
*******************************************************************************/


/*******************************************************************************
   Please config the touch panel in touch.h
 ******************************************************************************/
#include "touch.h"

#ifdef USE_UI
/* Change to your screen resolution */
static uint32_t screenWidth;
static uint32_t screenHeight;
static lv_disp_draw_buf_t draw_buf;
static lv_color_t disp_draw_buf[800 * 480 / 10];   //notice here!!!  5,7inch: lv_color_t disp_draw_buf[800*480/10]            4.3inch: lv_color_t disp_draw_buf[480*272/10]
//static lv_color_t disp_draw_buf;
static lv_disp_drv_t disp_drv;

int led_flag = 0;
int led_flag_Lock = 0;
// Variables to hold sensor readings
int  temp;
int  hum;

unsigned long previousMillis = 0;   // Stores last time temperature was published
const long interval_time = 10000;        // Interval at which to publish sensor readings

/* Display flushing */
void my_disp_flush(lv_disp_drv_t *disp, const lv_area_t *area, lv_color_t *color_p)
{
  uint32_t w = (area->x2 - area->x1 + 1);
  uint32_t h = (area->y2 - area->y1 + 1);

#if (LV_COLOR_16_SWAP != 0)
  lcd.pushImageDMA(area->x1, area->y1, w, h, (lgfx::rgb565_t*)&color_p->full);
#else
  lcd.pushImageDMA(area->x1, area->y1, w, h, (lgfx::rgb565_t*)&color_p->full);
#endif

  lv_disp_flush_ready(disp);
}

void my_touchpad_read(lv_indev_drv_t *indev_driver, lv_indev_data_t *data)
{
  if (touch_has_signal())
  {
    if (touch_touched())
    {
      data->state = LV_INDEV_STATE_PR;

      /*Set the coordinates*/
      data->point.x = touch_last_x;
      data->point.y = touch_last_y;
      Serial.print( "Data x :" );
      Serial.println( touch_last_x );

      Serial.print( "Data y :" );
      Serial.println( touch_last_y );
    }
    else if (touch_released())
    {
      data->state = LV_INDEV_STATE_REL;
    }
  }
  else
  {
    data->state = LV_INDEV_STATE_REL;
  }
  delay(15);
}
#endif

void connectToWifi() {
  Serial.println("Connecting to Wi-Fi...");
  WiFi.begin(WIFI_SSID, WIFI_PASSWORD);
}

void connectToMqtt() {
  Serial.println("Connecting to MQTT...");
  mqttClient.connect();
}

void WiFiEvent(WiFiEvent_t event) {
  Serial.printf("[WiFi-event] event: %d\n", event);
  switch (event) {
    case SYSTEM_EVENT_STA_GOT_IP:
      Serial.println("WiFi connected");
      Serial.println("IP address: ");
      Serial.println(WiFi.localIP());
      connectToMqtt();
      break;
    case SYSTEM_EVENT_STA_DISCONNECTED:
      Serial.println("WiFi lost connection");
      xTimerStop(mqttReconnectTimer, 0); // ensure we don't reconnect to MQTT while reconnecting to Wi-Fi
      xTimerStart(wifiReconnectTimer, 0);
      break;
  }
}

void onMqttConnect(bool sessionPresent) {
  Serial.println("Connected to MQTT.");
  Serial.print("Session present: ");
  Serial.println(sessionPresent);
  uint16_t packetIdSub = mqttClient.subscribe(MQTT_PUB_LED_C, 2);
  Serial.print("Subscribing at QoS 2, packetId: ");
  Serial.println(packetIdSub);
}

void onMqttDisconnect(AsyncMqttClientDisconnectReason reason) {
  Serial.println("Disconnected from MQTT.");
  if (WiFi.isConnected()) {
    xTimerStart(mqttReconnectTimer, 0);
  }
}

void onMqttSubscribe(uint16_t packetId, uint8_t qos) {
  Serial.println("Subscribe acknowledged.");
  Serial.print("  packetId: ");
  Serial.println(packetId);
  Serial.print("  qos: ");
  Serial.println(qos);
}

void onMqttUnsubscribe(uint16_t packetId) {
  Serial.println("Unsubscribe acknowledged.");
  Serial.print("  packetId: ");
  Serial.println(packetId);
}

void onMqttMessage(char* topic, char* payload, AsyncMqttClientMessageProperties properties, size_t len, size_t index, size_t total)
{
  Serial.println("Publish received.");
  for (int i = 0; i < len; i++) {
    Serial.print((char) payload[i]);
  }
  Serial.println("");
  if (strncmp(payload, "ON", 2) == 0) {
    digitalWrite(LED, HIGH);
    mqttClient.publish(MQTT_PUB_LED_S, 0, true, "ON");
    lv_obj_add_state(ui_Switch2, LV_STATE_CHECKED);
    lv_label_set_text(ui_Label6, "ON");
  }
  if (strncmp(payload, "OFF", 3) == 0) {
    digitalWrite(LED, LOW);
    mqttClient.publish(MQTT_PUB_LED_S, 0, true, "OFF");
    lv_obj_clear_state(ui_Switch2, LV_STATE_CHECKED);
    lv_label_set_text(ui_Label6, "OFF");
  }
}

void onMqttPublish(uint16_t packetId) {
  Serial.print("Publish acknowledged.");
  Serial.print("  packetId: ");
  Serial.println(packetId);
}

void setup()
{
  //IO Port Pins
  pinMode(LED, OUTPUT);
  digitalWrite(LED, LOW);
  pinMode(17, OUTPUT);
  digitalWrite(17, LOW);
  pinMode(18, OUTPUT);
  digitalWrite(18, LOW);
  pinMode(42, OUTPUT);
  digitalWrite(42, LOW);
  Serial.begin(9600);
  Wire.begin(19, 20);
  Serial.println();
  dht20.begin();
  mqttReconnectTimer = xTimerCreate("mqttTimer", pdMS_TO_TICKS(2000), pdFALSE, (void*)0, reinterpret_cast<TimerCallbackFunction_t>(connectToMqtt));
  wifiReconnectTimer = xTimerCreate("wifiTimer", pdMS_TO_TICKS(2000), pdFALSE, (void*)0, reinterpret_cast<TimerCallbackFunction_t>(connectToWifi));
  WiFi.onEvent(WiFiEvent);
  mqttClient.onConnect(onMqttConnect);
  mqttClient.onDisconnect(onMqttDisconnect);
  mqttClient.onSubscribe(onMqttSubscribe);
  mqttClient.onUnsubscribe(onMqttUnsubscribe);
  mqttClient.onMessage(onMqttMessage);
  mqttClient.onPublish(onMqttPublish);
  mqttClient.setServer(MQTT_HOST, MQTT_PORT);
  // If your broker requires authentication (username and password), set them below
  mqttClient.setCredentials(mqtt_username, mqtt_password);
  connectToWifi();

  // Init Display
  lcd.begin();
  lcd.fillScreen(TFT_BLACK);
  lcd.setTextSize(2);
  delay(200);

#ifdef USE_UI
  lv_init();

  delay(100);
  touch_init();

  screenWidth = lcd.width();
  screenHeight = lcd.height();

  lv_disp_draw_buf_init(&draw_buf, disp_draw_buf, NULL, screenWidth * screenHeight / 10);
  //  lv_disp_draw_buf_init(&draw_buf, disp_draw_buf, NULL, 480 * 272 / 10);
  /* Initialize the display */
  lv_disp_drv_init(&disp_drv);
  /* Change the following line to your display resolution */
  disp_drv.hor_res = screenWidth;
  disp_drv.ver_res = screenHeight;
  disp_drv.flush_cb = my_disp_flush;
  disp_drv.draw_buf = &draw_buf;
  lv_disp_drv_register(&disp_drv);

  /* Initialize the (dummy) input device driver */
  static lv_indev_drv_t indev_drv;
  lv_indev_drv_init(&indev_drv);
  indev_drv.type = LV_INDEV_TYPE_POINTER;
  indev_drv.read_cb = my_touchpad_read;
  lv_indev_drv_register(&indev_drv);
#endif

#ifdef TFT_BL
  pinMode(TFT_BL, OUTPUT);
  digitalWrite(TFT_BL, HIGH);
#endif

#ifdef USE_UI
  ui_init();//ui from Squareline or GUI Guider
#else
  lcd.fillScreen(TFT_RED);
  delay(800);
  lcd.fillScreen(TFT_BLUE);
  delay(800);
  lcd.fillScreen(TFT_YELLOW);
  delay(800);
  lcd.fillScreen(TFT_GREEN);
  delay(800);
#endif
  Serial.println( "Setup done" );
}

char buffer_t[10];
char buffer_h[10];


void loop()
{
#ifdef USE_UI
  lv_timer_handler();
  delay(5);
#endif
  if (led_flag_Lock == 1)
  {
    if (led_flag == 1)
    {
      led_flag_Lock = 0;
      digitalWrite(LED, HIGH);
      mqttClient.publish(MQTT_PUB_LED_S, 0, true, "ON");
    }
    else
    {
      led_flag_Lock = 0;
      digitalWrite(LED, LOW);
      mqttClient.publish(MQTT_PUB_LED_S, 0, true, "OFF");
    }
  }
  unsigned long currentMillis = millis();
  if (currentMillis - previousMillis >= interval_time)
  {
    previousMillis = currentMillis;
    // New DHT sensor readings
    hum = (int)dht20.getHumidity();
    // Read temperature as Celsius (the default)
    temp = (int)dht20.getTemperature();
    Serial.print("hum:");
    Serial.println( hum);
    Serial.print("temp:");
    Serial.println( temp);
    itoa(hum, buffer_h, 10);
    itoa(temp, buffer_t, 10);
    lv_label_set_text(ui_Label2, buffer_t);
    lv_label_set_text(ui_Label3, buffer_h);
    if (isnan(temp) || isnan(hum))
    {
      Serial.println(F("Failed to read from DHT20 sensor!"));
      return;
    }
    // Publish an MQTT message on topic esp32/dht20/temperature
    uint16_t packetIdPub1 = mqttClient.publish(MQTT_PUB_TEMP, 0, true, String(temp).c_str());
    Serial.printf("Publishing on topic %s at QoS 1, packetId: %i", MQTT_PUB_TEMP, packetIdPub1);
    Serial.printf("Message: %.2f \n", temp);
    // Publish an MQTT message on topic esp32/dht20/humidity
    uint16_t packetIdPub2 = mqttClient.publish(MQTT_PUB_HUM, 0, true, String(hum).c_str());
    Serial.printf("Publishing on topic %s at QoS 1, packetId %i: ", MQTT_PUB_HUM, packetIdPub2);
    Serial.printf("Message: %.2f \n", hum);
  }
}

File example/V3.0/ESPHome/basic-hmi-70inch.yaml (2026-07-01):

esphome:
  name: basic-hmi-70inch
  friendly_name: Basic_HMI_7.0inch
  platformio_options:                                        # Custom PlatformIO build configuration
    build_flags: 
      - "-DBOARD_HAS_PSRAM"                                  # Enable PSRAM support in compilation
    board_build.esp-idf.memory_type: qio_opi                 # Set memory type for ESP-IDF framework
    board_build.flash_mode: dio                              # Set SPI flash access mode to DIO

  on_boot:                                                   # Actions to execute during boot phase
    priority: 600                                            # High priority to run before most components
    then: 
      - lambda: |- 
          uint8_t addr = 0x18;                               // PCA9557 I2C expander slave address
          
          uint8_t config[2] = {0x03, 0x00};                  // 1. Set all PCA9557 pins as outputs
          id(bus_a).write(addr, config, 2);                  // Write configuration via I2C bus
          
          uint8_t output_low[2] = {0x01, 0x00};              // 2. IO0=LOW, IO1=LOW (Hard reset GT911)
          id(bus_a).write(addr, output_low, 2);              // Apply low signals to reset pins
          
          delay(20);                                         // 3. Hold reset state for 20 milliseconds
          
          uint8_t output_high[2] = {0x01, 0x01};             // 4. IO0=HIGH (Release GT911 reset sequence)
          id(bus_a).write(addr, output_high, 2);             // Apply high signal to wake up touch IC
          
          delay(100);                                        // 5. Wait 100ms for touch IC to initialize
          
          uint8_t config_input[2] = {0x03, 0x02};            // 6. Set IO1 as input for GT911 interrupt
          id(bus_a).write(addr, config_input, 2);            // Finalize PCA9557 pin configuration

esp32:                                                       # ESP32 specific hardware configuration
  board: esp32s3box                                          # Base board model for ESP32-S3
  framework: 
    type: esp-idf                                            # Use official ESP-IDF framework, not Arduino
    sdkconfig_options: 
      CONFIG_ESP32S3_DEFAULT_CPU_FREQ_240: y                 # Set CPU frequency to max (240MHz)
      CONFIG_ESP32S3_DATA_CACHE_64KB: y                      # Allocate 64KB for data cache
      CONFIG_SPIRAM_FETCH_INSTRUCTIONS: y                    # Allow instruction fetch from SPIRAM
      CONFIG_SPIRAM_RODATA: y                                # Store read-only data in SPIRAM
      CONFIG_SPIRAM_USE: y                                   # Enable external SPIRAM globally
      CONFIG_SPIRAM_SPEED_80M: y                             # Set SPIRAM clock speed to 80MHz
      CONFIG_SPIRAM_MODE_OCT: y                              # Use Octal mode for faster RAM access
      CONFIG_ESP32S3_SPIRAM_SUPPORT: y                       # Enable ESP32-S3 specific SPIRAM support
  variant: esp32s3                                           # Specify the chip variant exactly

psram:                                                       # Physical PSRAM configuration block
  mode: octal                                                # Octal SPI mode matches board layout
  speed: 80MHz                                               # 80MHz speed matches sdkconfig options

# Enable logging
logger:

# Enable Home Assistant API
api:
  encryption:
    key: "fYU7uv1hXlQofCz0Pg52T135qknI1T2Y8kMpiPACnq4="

ota:
  - platform: esphome
    password: "ed31b1ea0257a84085db2485b8eeb4a1"

wifi:
  ssid: !secret wifi_ssid
  password: !secret wifi_password

  # Enable fallback hotspot (captive portal) in case wifi connection fails
  ap:
    ssid: "Basic-Hmi-70Inch"
    password: "f9XVlSaUD4ao"

captive_portal:
    

output:                                                      # Hardware output definitions
  - platform: ledc                                           # Use ESP32 LEDC hardware PWM controller
    pin: 2                                                   # GPIO 2 controls the display backlight
    frequency: 1220                                          # 1220 Hz PWM frequency prevents flickering
    id: gpio_backlight_pwm                                   # Internal ID to link with light component

light:                                                       # Light entities exposed to Home Assistant
  - platform: monochromatic                                  # Single-color brightness-controlled light
    output: gpio_backlight_pwm                               # Link to the PWM output defined above
    name: Display Backlight                                  # Entity name shown in Home Assistant
    id: back_light                                           # Internal ID for automation reference
    restore_mode: ALWAYS_ON                                  # Ensure screen turns on after power loss
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

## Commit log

2026-04-19 Replace Arduino image in README
    Updated image link in the README file.
2026-06-16 Move ESP_IDF examples to V1.0_and_V2.0
    [app3M_fat9M_16MB.csv, code-format.cfg, default.csv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]

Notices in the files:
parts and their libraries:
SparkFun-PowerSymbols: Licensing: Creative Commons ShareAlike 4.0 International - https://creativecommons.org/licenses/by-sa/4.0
